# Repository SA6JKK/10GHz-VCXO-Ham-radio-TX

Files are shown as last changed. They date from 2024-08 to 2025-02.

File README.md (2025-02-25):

# 10GHz-VCXO-Ham-radio-TX
 A 10 GHz VCXO based FSK transmitter for ham radio

Goal: 0dBm to antenna. 

Goal: Output frequency between 10367-10369 MHz.  

Goal 75x120 mm PCB that fits HAMMOND 1455J1201RD 

https://se.farnell.com/hammond/1455j1201rd/pcb-box-enclosure-alum-red/dp/2469294

VCXO control from external BNC connector. FSK-CW or FSK modes. 

Aisler four layer "HD PCB" stackup for somewhat close to 50 ohms with cheap FR4 substrate. 

# Project Status: 

Schematic: Finished 

Layout: Finished and ordered

Verification: Not fully working :(

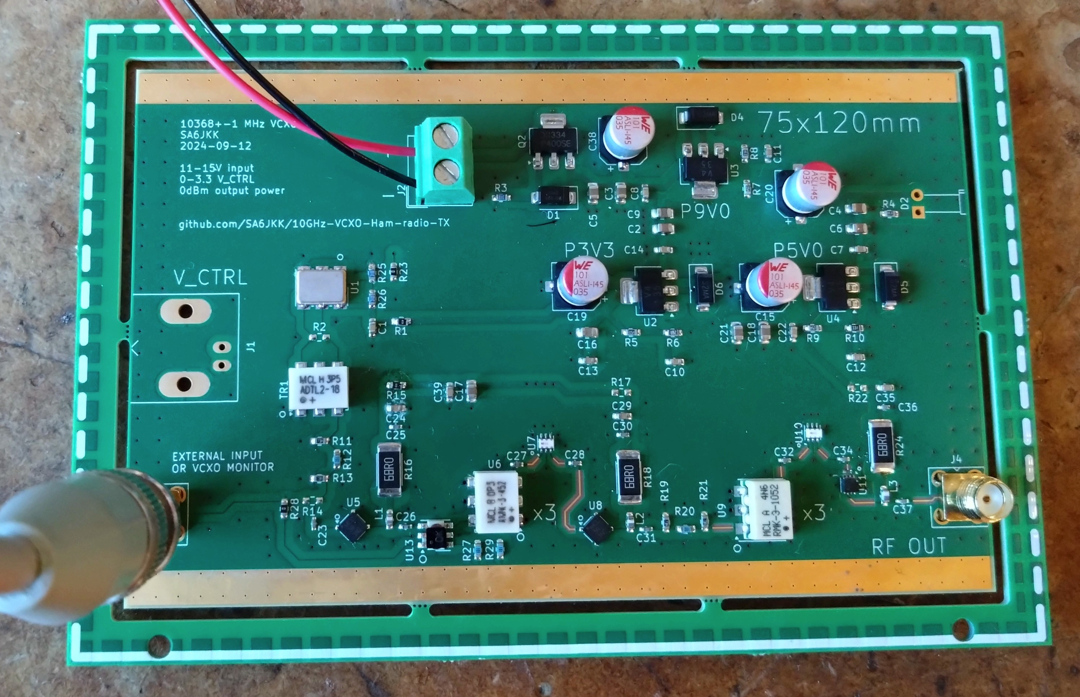
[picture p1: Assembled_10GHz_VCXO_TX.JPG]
Assembled PCB


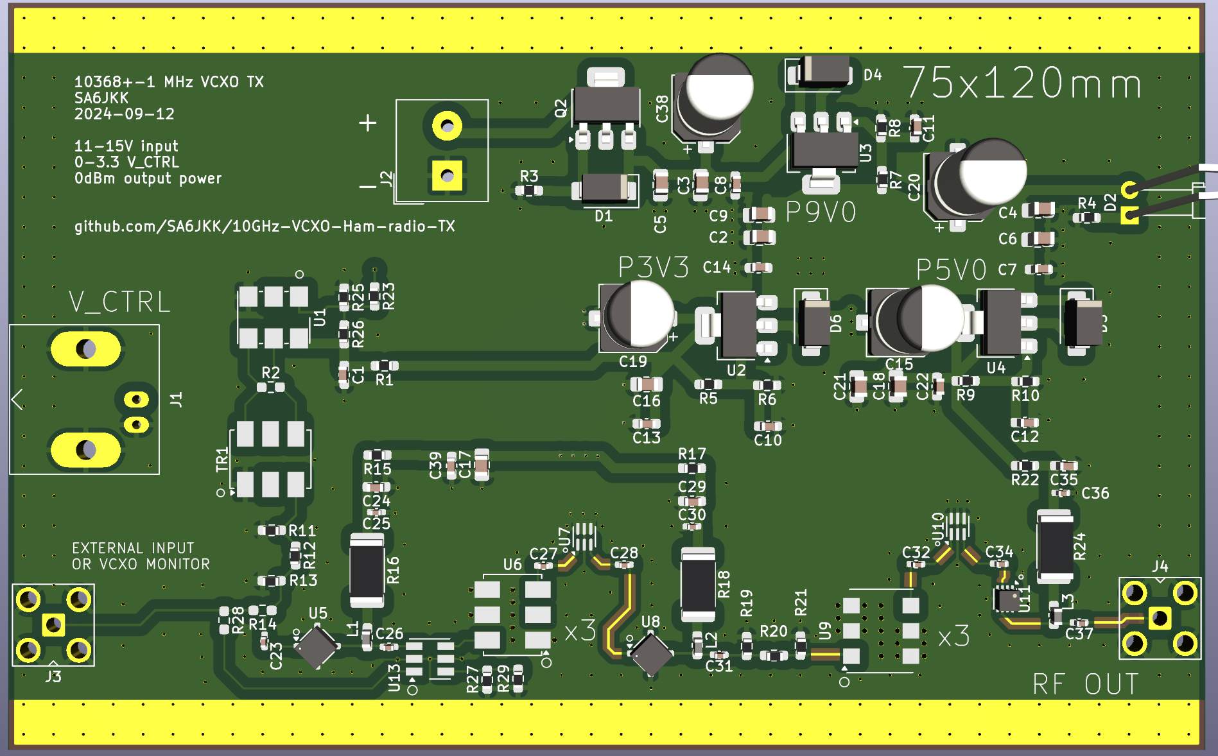
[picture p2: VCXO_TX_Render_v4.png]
Render of PCB


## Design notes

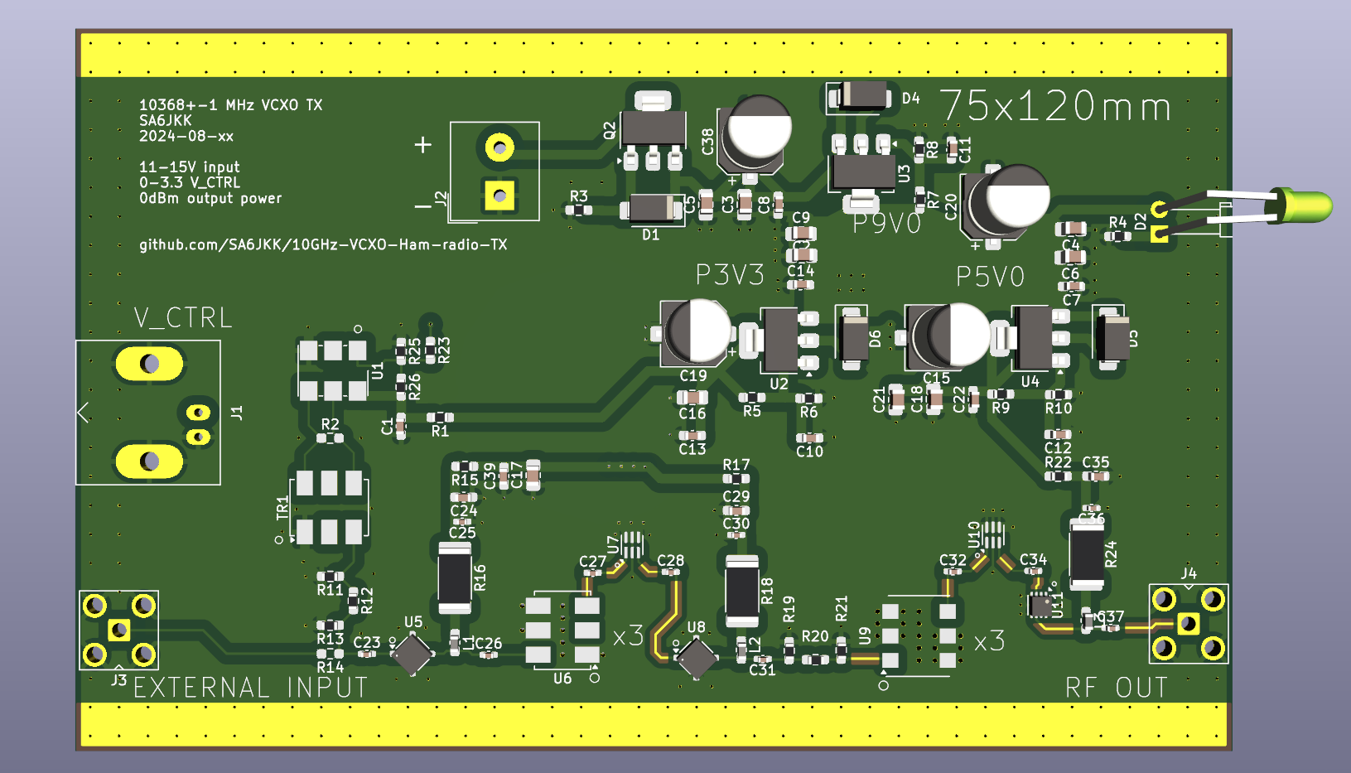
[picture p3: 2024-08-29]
VCXO_TX_Render_v2.png

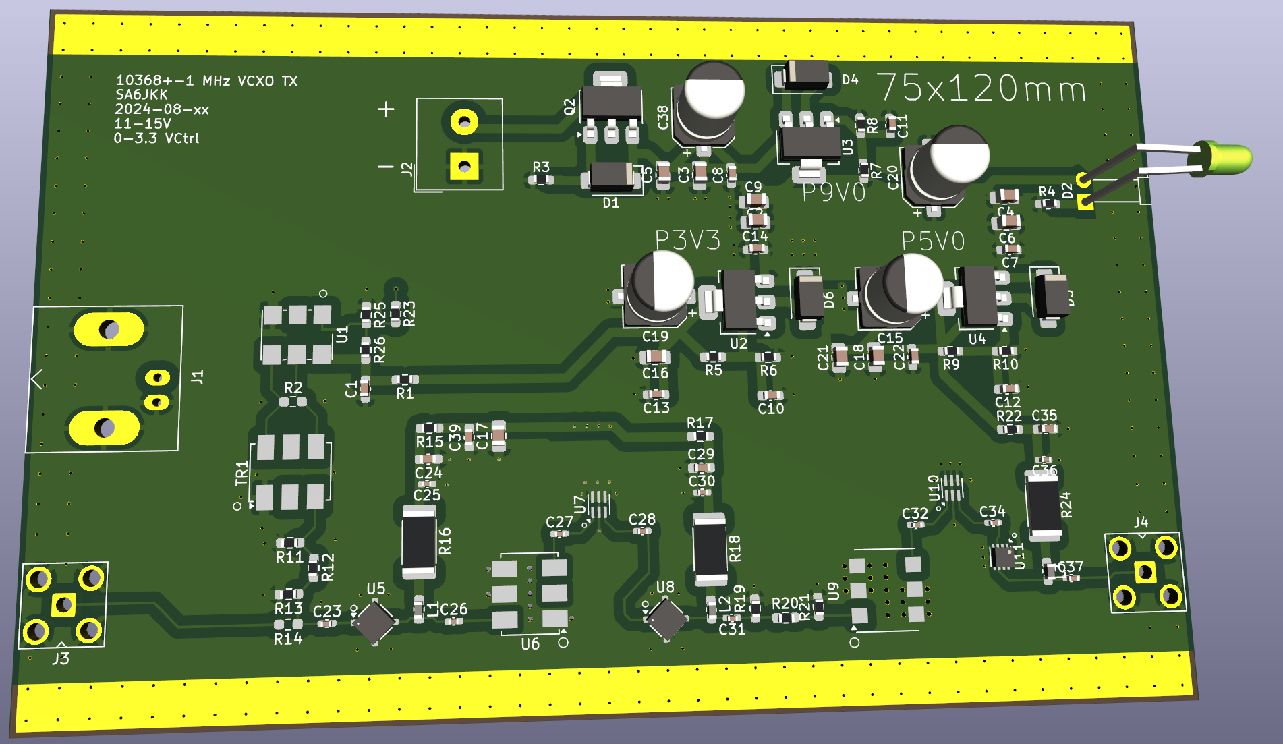
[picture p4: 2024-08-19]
VCXO_TX_Render_v1.png

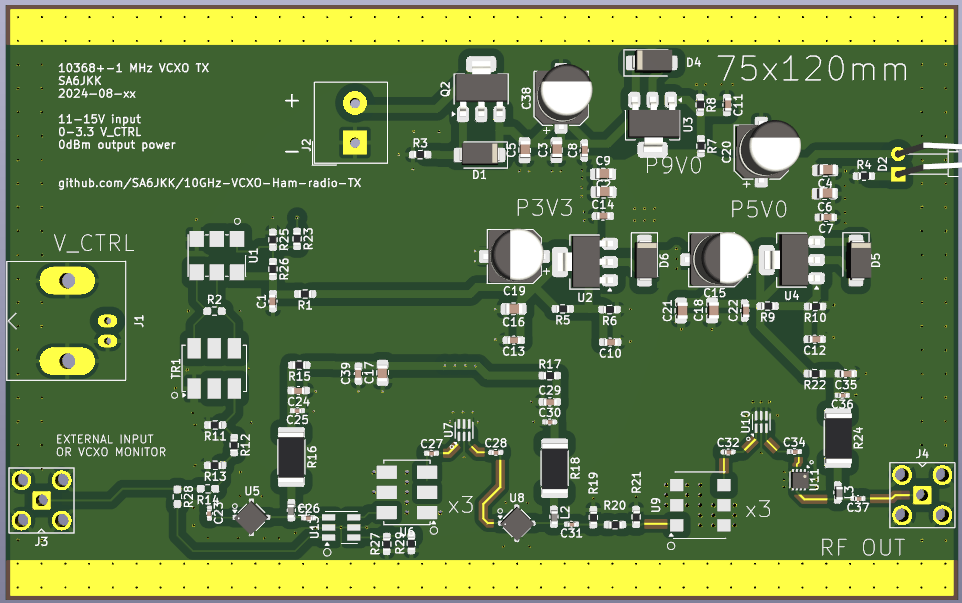
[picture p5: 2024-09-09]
VCXO_TX_Render_v3.png

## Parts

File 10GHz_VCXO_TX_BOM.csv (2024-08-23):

Reference | Value | Datasheet | Footprint | Qty | DNP
C1,C7,C8,C10,C11,C12,C13,C14,C22,C24,C29,C35,C39 | 100nF | ~ | Capacitor_SMD:C_0603_1608Metric_Pad1.08x0.95mm_HandSolder | 13
C2,C3,C4,C5,C6,C9,C16,C17,C18,C21 | 10uF | ~ | Capacitor_SMD:C_0805_2012Metric_Pad1.18x1.45mm_HandSolder | 10
C15,C19,C20,C38 | 100uF | ~ | Capacitor_SMD:CP_Elec_6.3x7.7 | 4
C23,C25,C26,C27,C28,C30,C31,C32,C34,C36,C37 | 1nF | ~ | Capacitor_SMD:C_0402_1005Metric_Pad0.74x0.62mm_HandSolder | 11
D1 | 10V | ~ | Diode_SMD:D_SMA | 1
D2 | LED | ~ | LED_THT:LED_D3.0mm_Horizontal_O6.35mm_Z10.0mm | 1
D4,D5,D6 | S2MA | https://www.farnell.com/datasheets/2863973.pdf | Diode_SMD:D_SMA | 3
J1,J3,J4 | Conn_Coaxial | ~ | -- mixed values -- | 3
J2 | Screw_Terminal_01x02 | ~ | TerminalBlock_Altech:Altech_AK100_1x02_P5.00mm | 1
L1 | 27nH | ~ | Inductor_SMD:L_0603_1608Metric_Pad1.05x0.95mm_HandSolder | 1
L2 | 10nH | ~ | Inductor_SMD:L_0603_1608Metric_Pad1.05x0.95mm_HandSolder | 1
L3 | 2.7nH | ~ | Inductor_SMD:L_0603_1608Metric_Pad1.05x0.95mm_HandSolder | 1
Q2 | DMP10H400SE | https://www.farnell.com/datasheets/2814417.pdf | Package_TO_SOT_SMD:SOT-223-3_TabPin2 | 1
R1,R15,R17,R22,R23 | 0 | ~ | Resistor_SMD:R_0603_1608Metric_Pad0.98x0.95mm_HandSolder | 5
R2 | 100 | ~ | Resistor_SMD:R_0603_1608Metric_Pad0.98x0.95mm_HandSolder | 1 | DNP
R3,R25,R26 | 10k | ~ | Resistor_SMD:R_0603_1608Metric_Pad0.98x0.95mm_HandSolder | 3
R4 | R? | ~ | Resistor_SMD:R_0603_1608Metric_Pad0.98x0.95mm_HandSolder | 1
R5,R7,R9 | 110 | ~ | Resistor_SMD:R_0603_1608Metric_Pad0.98x0.95mm_HandSolder | 3
R6 | 180 | ~ | Resistor_SMD:R_0603_1608Metric_Pad0.98x0.95mm_HandSolder | 1
R8 | 680 | ~ | Resistor_SMD:R_0603_1608Metric_Pad0.98x0.95mm_HandSolder | 1
R10 | 330 | ~ | Resistor_SMD:R_0603_1608Metric_Pad0.98x0.95mm_HandSolder | 1
R11,R13,R19,R21 | 560 | ~ | Resistor_SMD:R_0603_1608Metric_Pad0.98x0.95mm_HandSolder | 4
R12,R20 | 10 | ~ | Resistor_SMD:R_0603_1608Metric_Pad0.98x0.95mm_HandSolder | 2
R14 | 0 | ~ | Resistor_SMD:R_0603_1608Metric_Pad0.98x0.95mm_HandSolder | 1 | DNP
R16,R18,R24 | 68 | ~ | Resistor_SMD:R_2512_6332Metric_Pad1.40x3.35mm_HandSolder | 3
TR1 | ADTL2-18 2:1 | https://www.minicircuits.com/pdfs/ADTL2-18+.pdf | RF_Mini-Circuits:Mini-Circuits_CD542_H2.84mm | 1
U1 | 1152MHz | https://www.renesas.com/us/en/document/dst/xu-family-low-phase-noise-quartz-based-pll-oscillators-datasheet | Oscillator:Oscillator_SMD_IDT_JU6-6_7.0x5.0mm_P2.54mm | 1
U2,U3,U4 | TLV1117-ADJ | http://www.ti.com/lit/ds/symlink/tlv1117.pdf | Package_TO_SOT_SMD:SOT-223-3_TabPin2 | 3
U5,U8 | LEE-59+ | https://www.mouser.se/datasheet/2/1030/LEE_59_2b-1700827.pdf | Package_DFN_QFN:Mini-Circuits_FG873-4_3x3mm | 2
U6 | AMK-3-452+ | https://www.mouser.se/datasheet/2/1030/AMK_3_452_2b-2936698.pdf | RF_Mini-Circuits:Mini-Circuits_CD542_LandPatternPL-052 | 1
U7 | HFCG-2200+ | https://www.mouser.se/datasheet/2/1030/HFCG_2200_2b-3077494.pdf | OptoDevice:Broadcom_DFN-6_2x2mm_P0.65mm | 1
U9 | RMK-3-1052+ | https://www.mouser.se/datasheet/2/1030/RMK_3_1052_2b-3305585.pdf | RF_Mini-Circuits:Mini-Circuits_TT1224_LandPatternPL-258_ClockwisePinNumbering | 1
U10 | HFCG-4400+ | https://www.mouser.se/datasheet/2/1030/HFCG_4400_2b-2256271.pdf | OptoDevice:Broadcom_DFN-6_2x2mm_P0.65mm | 1
U11 | PMA2-123LN5+ | https://www.mouser.se/datasheet/2/1030/PMA2_123LN5_2b-1701048.pdf | Package_DFN_QFN:DFN-8-1EP_2x2mm_P0.5mm_EP0.6x1.2mm | 1

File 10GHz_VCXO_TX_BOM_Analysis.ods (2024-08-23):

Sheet: BOM_v3
Reference | Value | Datasheet | Footprint | Qty | DNP | Ordered
C1,C7,C8,C10,C11,C12,C13,C14,C22,C24,C29,C35,C39 | 100nF | ~ | Capacitor_SMD:C_0603_1608Metric_Pad1.08x0.95mm_HandSolder | 13 |  | 100
C2,C3,C4,C5,C6,C9,C16,C17,C18,C21 | 10uF | ~ | Capacitor_SMD:C_0805_2012Metric_Pad1.18x1.45mm_HandSolder | 10 |  | 30
C15,C19,C20,C38 | 100uF | ~ | Capacitor_SMD:CP_Elec_6.3x7.7 | 4 |  | 20
C23,C25,C26,C27,C28,C30,C31,C32,C34,C36,C37 | 1nF | ~ | Capacitor_SMD:C_0402_1005Metric_Pad0.74x0.62mm_HandSolder | 11 |  | 30
D1 | 10V | ~ | Diode_SMD:D_SMA | 1 |  | 10
D2 | LED | ~ | LED_THT:LED_D3.0mm_Horizontal_O6.35mm_Z10.0mm | 1 |  | Inventory
D4,D5,D6 | S2MA | https://www.farnell.com/datasheets/2863973.pdf | Diode_SMD:D_SMA | 3 |  | 30
J1,J3,J4 | Conn_Coaxial | ~ | -- mixed values -- | 3 |  | Inventory
J2 | Screw_Terminal_01x02 | ~ | TerminalBlock_Altech:Altech_AK100_1x02_P5.00mm | 1 |  | Inventory
L1 | 27nH | ~ | Inductor_SMD:L_0603_1608Metric_Pad1.05x0.95mm_HandSolder | 1 |  | 20
L2 | 10nH | ~ | Inductor_SMD:L_0603_1608Metric_Pad1.05x0.95mm_HandSolder | 1 |  | 20
L3 | 2.7nH | ~ | Inductor_SMD:L_0603_1608Metric_Pad1.05x0.95mm_HandSolder | 1 |  | 20
Q2 | DMP10H400SE | https://www.farnell.com/datasheets/2814417.pdf | Package_TO_SOT_SMD:SOT-223-3_TabPin2 | 1 |  | 10
R1,R15,R17,R22,R23 | 0 | ~ | Resistor_SMD:R_0603_1608Metric_Pad0.98x0.95mm_HandSolder | 5 |  | Inventory
R2 | 100 | ~ | Resistor_SMD:R_0603_1608Metric_Pad0.98x0.95mm_HandSolder | 1 | DNP | Inventory
R3,R25,R26 | 10k | ~ | Resistor_SMD:R_0603_1608Metric_Pad0.98x0.95mm_HandSolder | 3 |  | Inventory
R4 | R? | ~ | Resistor_SMD:R_0603_1608Metric_Pad0.98x0.95mm_HandSolder | 1 |  | Inventory
R5,R7,R9 | 110 | ~ | Resistor_SMD:R_0603_1608Metric_Pad0.98x0.95mm_HandSolder | 3 |  | Inventory
R6 | 180 | ~ | Resistor_SMD:R_0603_1608Metric_Pad0.98x0.95mm_HandSolder | 1 |  | Inventory
R8 | 680 | ~ | Resistor_SMD:R_0603_1608Metric_Pad0.98x0.95mm_HandSolder | 1 |  | Inventory
R10 | 330 | ~ | Resistor_SMD:R_0603_1608Metric_Pad0.98x0.95mm_HandSolder | 1 |  | Inventory
R11,R13,R19,R21 | 560 | ~ | Resistor_SMD:R_0603_1608Metric_Pad0.98x0.95mm_HandSolder | 4 |  | Inventory
R12,R20 | 10 | ~ | Resistor_SMD:R_0603_1608Metric_Pad0.98x0.95mm_HandSolder | 2 |  | Inventory
R14 | 0 | ~ | Resistor_SMD:R_0603_1608Metric_Pad0.98x0.95mm_HandSolder | 1 | DNP | Inventory
R16,R18,R24 | 68 | ~ | Resistor_SMD:R_2512_6332Metric_Pad1.40x3.35mm_HandSolder | 3 |  | Inventory
TR1 | ADTL2-18 2:1 | https://www.minicircuits.com/pdfs/ADTL2-18+.pdf | RF_Mini-Circuits:Mini-Circuits_CD542_H2.84mm | 1 |  | 3
U1 | 1152MHz | https://www.renesas.com/us/en/document/dst/xu-family-low-phase-noise-quartz-based-pll-oscillators-datasheet | Oscillator:Oscillator_SMD_IDT_JU6-6_7.0x5.0mm_P2.54mm | 1 |  | 5
U2,U3,U4 | TLV1117-ADJ | http://www.ti.com/lit/ds/symlink/tlv1117.pdf | Package_TO_SOT_SMD:SOT-223-3_TabPin2 | 3 |  | 15
U5,U8 | LEE-59+ | https://www.mouser.se/datasheet/2/1030/LEE_59_2b-1700827.pdf | Package_DFN_QFN:Mini-Circuits_FG873-4_3x3mm | 2 |  | Inventory
U6 | AMK-3-452+ | https://www.mouser.se/datasheet/2/1030/AMK_3_452_2b-2936698.pdf | RF_Mini-Circuits:Mini-Circuits_CD542_LandPatternPL-052 | 1 |  | 3
U7 | HFCG-2200+ | https://www.mouser.se/datasheet/2/1030/HFCG_2200_2b-3077494.pdf | OptoDevice:Broadcom_DFN-6_2x2mm_P0.65mm | 1 |  | 3
U9 | RMK-3-1052+ | https://www.mouser.se/datasheet/2/1030/RMK_3_1052_2b-3305585.pdf | RF_Mini-Circuits:Mini-Circuits_TT1224_LandPatternPL-258_ClockwisePinNumbering | 1 |  | 3
U10 | HFCG-4400+ | https://www.mouser.se/datasheet/2/1030/HFCG_4400_2b-2256271.pdf | OptoDevice:Broadcom_DFN-6_2x2mm_P0.65mm | 1 |  | 3
U11 | PMA2-123LN5+ | https://www.mouser.se/datasheet/2/1030/PMA2_123LN5_2b-1701048.pdf | Package_DFN_QFN:DFN-8-1EP_2x2mm_P0.5mm_EP0.6x1.2mm | 1 |  | 3

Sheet: BOM_v2
Reference | Value | Datasheet | Footprint | Qty | DNP | Cost estimate | Total cost
C1,C7,C8,C10,C11,C12,C13,C14,C22,C24,C29,C35,C39 | 100nF | ~ | Capacitor_SMD:C_0603_1608Metric_Pad1.08x0.95mm_HandSolder | 13 |  | 1 | 13
C2,C3,C4,C5,C6,C9,C18,C21 | 10uF | ~ | Capacitor_SMD:C_0603_1608Metric_Pad1.08x0.95mm_HandSolder | 8 |  | 1 | 8
C15,C19,C20,C38 | 100uF | ~ | Capacitor_SMD:CP_Elec_5x5.7 | 4 |  | 1 | 4
C16,C17 | >1u | ~ | Capacitor_SMD:C_0603_1608Metric_Pad1.08x0.95mm_HandSolder | 2 |  | 1 | 2
C23,C25,C26,C27,C28,C30,C31,C32,C33,C34,C36,C37 | 1nF | ~ | Capacitor_SMD:C_0402_1005Metric_Pad0.74x0.62mm_HandSolder | 12 |  | 1 | 12
D1 | 10V | ~ | Package_TO_SOT_SMD:SOT-223-3_TabPin2 | 1 |  | 2 | 2
D3 | LED | ~ | LED_THT:LED_D3.0mm_Horizontal_O6.35mm_Z10.0mm | 1 |  | 2 | 2
D7,D8,D9 | 1N4002 | http://www.vishay.com/docs/88503/1n4001.pdf | Diode_THT:D_DO-41_SOD81_P10.16mm_Horizontal | 3 |  | 2 | 6
J1,J3,J4 | Conn_Coaxial | ~ | -- mixed values -- | 3 |  | 50 | 150
J2 | Screw_Terminal_01x02 | ~ | TerminalBlock_Altech:Altech_AK100_1x02_P5.00mm | 1 |  | 2 | 2
L1,L2,L3 | L | ~ | Inductor_SMD:L_0603_1608Metric_Pad1.05x0.95mm_HandSolder | 3 |  | 3 | 9
Q2 | DMP10H400SE | https://www.farnell.com/datasheets/2814417.pdf | Package_TO_SOT_SMD:SOT-223-3_TabPin2 | 1 |  | 6 | 6
R1,R14,R15,R17,R22 | 0 | ~ | Resistor_SMD:R_0603_1608Metric_Pad0.98x0.95mm_HandSolder | 5 |  | 1 | 5
R2 | 100 | ~ | Resistor_SMD:R_0603_1608Metric_Pad0.98x0.95mm_HandSolder | 1 | DNP | 1 | 1
R3,R4 | R? | ~ | Resistor_SMD:R_0603_1608Metric_Pad0.98x0.95mm_HandSolder | 2 |  | 1 | 2
R5,R7,R9 | 110 | ~ | Resistor_SMD:R_0603_1608Metric_Pad0.98x0.95mm_HandSolder | 3 |  | 1 | 3
R6 | 180 | ~ | Resistor_SMD:R_0603_1608Metric_Pad0.98x0.95mm_HandSolder | 1 |  | 1 | 1
R8 | 680 | ~ | Resistor_SMD:R_0603_1608Metric_Pad0.98x0.95mm_HandSolder | 1 |  | 1 | 1
R10 | 330 | ~ | Resistor_SMD:R_0603_1608Metric_Pad0.98x0.95mm_HandSolder | 1 |  | 1 | 1
R11,R13,R19,R21 | 560 | ~ | Resistor_SMD:R_0603_1608Metric_Pad0.98x0.95mm_HandSolder | 4 |  | 1 | 4
R12,R20 | 10 | ~ | Resistor_SMD:R_0603_1608Metric_Pad0.98x0.95mm_HandSolder | 2 |  | 1 | 2
R16,R18,R24 | 68 | ~ | Resistor_SMD:R_2512_6332Metric_Pad1.40x3.35mm_HandSolder | 3 |  | 5 | 15
TR1 | ADTL2-18 2:1 | https://www.minicircuits.com/pdfs/ADTL2-18+.pdf | RF_Mini-Circuits:Mini-Circuits_CD542_H2.84mm | 1 |  | 69 | 69
U1 | 1152MHz | https://www.renesas.com/us/en/document/dst/xu-family-low-phase-noise-quartz-based-pll-oscillators-datasheet | Oscillator:Oscillator_SMD_IDT_JU6-6_7.0x5.0mm_P2.54mm | 1 |  | 68 | 68
U2,U3,U4 | TLV1117-ADJ | http://www.ti.com/lit/ds/symlink/tlv1117.pdf | Package_TO_SOT_SMD:SOT-223-3_TabPin2 | 3 |  | 5 | 15
U5,U8 | LEE-59+ | https://www.mouser.se/datasheet/2/1030/LEE_59_2b-1700827.pdf | Package_DFN_QFN:Mini-Circuits_FG873-4_3x3mm | 2 |  | 34 | 68
U6 | AMK-3-452+ | https://www.mouser.se/datasheet/2/1030/AMK_3_452_2b-2936698.pdf | RF_Mini-Circuits:Mini-Circuits_CD542_LandPatternPL-052 | 1 |  | 104 | 104
U7 | HFCG-2200+ | https://www.mouser.se/datasheet/2/1030/HFCG_2200_2b-3077494.pdf | OptoDevice:Broadcom_DFN-6_2x2mm_P0.65mm | 1 |  | 73 | 73
U9 | RMK-3-1052+ | https://www.mouser.se/datasheet/2/1030/RMK_3_1052_2b-3305585.pdf | RF_Mini-Circuits:Mini-Circuits_TT1224_LandPatternPL-258_ClockwisePinNumbering | 1 |  | 149 | 149
U10 | HFCG-4400+ | https://www.mouser.se/datasheet/2/1030/HFCG_4400_2b-2256271.pdf | OptoDevice:Broadcom_DFN-6_2x2mm_P0.65mm | 1 |  | 73 | 73
U11 | PMA2-123LN5+ | https://www.mouser.se/datasheet/2/1030/PMA2_123LN5_2b-1701048.pdf | Package_DFN_QFN:DFN-8-1EP_2x2mm_P0.5mm_EP0.6x1.2mm | 1 |  | 194 | 194
 |  |  |  | Last update | 2024-07-28 |  | 1015 | kr

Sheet: BOM_v1
Reference | Value | Datasheet | Footprint | Qty | DNP | Cost estimate | Total cost
C1,C4,C5,C6,C11,C12,C13,C16,C18 | 100nF | ~ | Capacitor_SMD:C_0603_1608Metric_Pad1.08x0.95mm_HandSolder | 9 |  | 1 | 9
C2,C3,C9,C10 | 10uF | ~ | Capacitor_SMD:C_0603_1608Metric_Pad1.08x0.95mm_HandSolder | 4 |  | 1 | 4
C7,C14 | >1u | ~ | Capacitor_SMD:C_0603_1608Metric_Pad1.08x0.95mm_HandSolder | 2 |  | 1 | 2
C8,C15 | 100uF | ~ | Capacitor_SMD:CP_Elec_5x5.7 | 2 |  | 1 | 2
C17,C19,C20,C21 | 1nF | ~ | Capacitor_SMD:C_0402_1005Metric_Pad0.74x0.62mm_HandSolder | 4 |  | 1 | 4
D1,D2 | 1N4002 | http://www.vishay.com/docs/88503/1n4001.pdf | Diode_THT:D_DO-41_SOD81_P10.16mm_Horizontal | 2 |  | 2 | 4
J1,J3 | Screw_Terminal_01x02 | ~ | TerminalBlock_Altech:Altech_AK100_1x02_P5.00mm | 2 |  | 2 | 4
J2 | Conn_Coaxial | ~ | Connector_Coaxial:SMA_Amphenol_901-143_Horizontal | 1 |  | 50 | 50
L1,L2 | L | ~ | Inductor_SMD:L_0603_1608Metric_Pad1.05x0.95mm_HandSolder | 2 |  | 3 | 6
R1 | 100 | ~ | Resistor_SMD:R_0603_1608Metric_Pad0.98x0.95mm_HandSolder | 1 | DNP | 1 | 1
R2,R7 | 110 | ~ | Resistor_SMD:R_0603_1608Metric_Pad0.98x0.95mm_HandSolder | 2 |  | 1 | 2
R3 | 180 | ~ | Resistor_SMD:R_0603_1608Metric_Pad0.98x0.95mm_HandSolder | 1 |  | 1 | 1
R4,R6,R11,R13 | 560 | ~ | Resistor_SMD:R_0603_1608Metric_Pad0.98x0.95mm_HandSolder | 4 |  | 1 | 4
R5,R12 | 10 | ~ | Resistor_SMD:R_0603_1608Metric_Pad0.98x0.95mm_HandSolder | 2 |  | 1 | 2
R8 | 680 | ~ | Resistor_SMD:R_0603_1608Metric_Pad0.98x0.95mm_HandSolder | 1 |  | 1 | 1
R9,R10 | 68 | ~ | Resistor_SMD:R_2512_6332Metric_Pad1.40x3.35mm_HandSolder | 2 |  | 5 | 10
R14,R15,R16 | 0 | ~ | Resistor_SMD:R_0603_1608Metric_Pad0.98x0.95mm_HandSolder | 3 |  | 1 | 3
TR1 | ADTL2-18 2:1 | https://www.minicircuits.com/pdfs/ADTL2-18+.pdf | RF_Mini-Circuits:Mini-Circuits_CD542_H2.84mm | 1 |  | 69 | 69
U1,U5 | TLV1117-ADJ | http://www.ti.com/lit/ds/symlink/tlv1117.pdf | Package_TO_SOT_SMD:SOT-223-3_TabPin2 | 2 |  | 5 | 10
U2 | 1152MHz | https://www.renesas.com/us/en/document/dst/xu-family-low-phase-noise-quartz-based-pll-oscillators-datasheet | Oscillator:Oscillator_SMD_IDT_JU6-6_7.0x5.0mm_P2.54mm | 1 |  | 68 | 68
U3 | AMK-3-452+ | https://www.mouser.se/datasheet/2/1030/AMK_3_452_2b-2936698.pdf | RF_Mini-Circuits:Mini-Circuits_CD542_LandPatternPL-052 | 1 |  | 104 | 104
U4 | RMK-3-1052+ | https://www.mouser.se/datasheet/2/1030/RMK_3_1052_2b-3305585.pdf | RF_Mini-Circuits:Mini-Circuits_TT1224_LandPatternPL-258_ClockwisePinNumbering | 1 |  | 149 | 149
U6,U7 | LEE-59+ | https://www.mouser.se/datasheet/2/1030/LEE_59_2b-1700827.pdf | Package_DFN_QFN:Mini-Circuits_FG873-4_3x3mm | 2 |  | 34 | 68
 |  |  |  | Last update | 2024-06-24 |  | 577 | kr

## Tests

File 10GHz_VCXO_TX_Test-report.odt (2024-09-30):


# Power

12V 250(?) mA, greater than 12V 188 mA expected

P9V0 OK

P5V0 OK

P3V3 OK

# TX_VCXO

Frequency OK, 1152 Mhz

# X3_IF_Multiplier

Coupler output 8dBm, 4-5 dB more than expected

Update schematic R11, R12, R13 to lower power into U5.

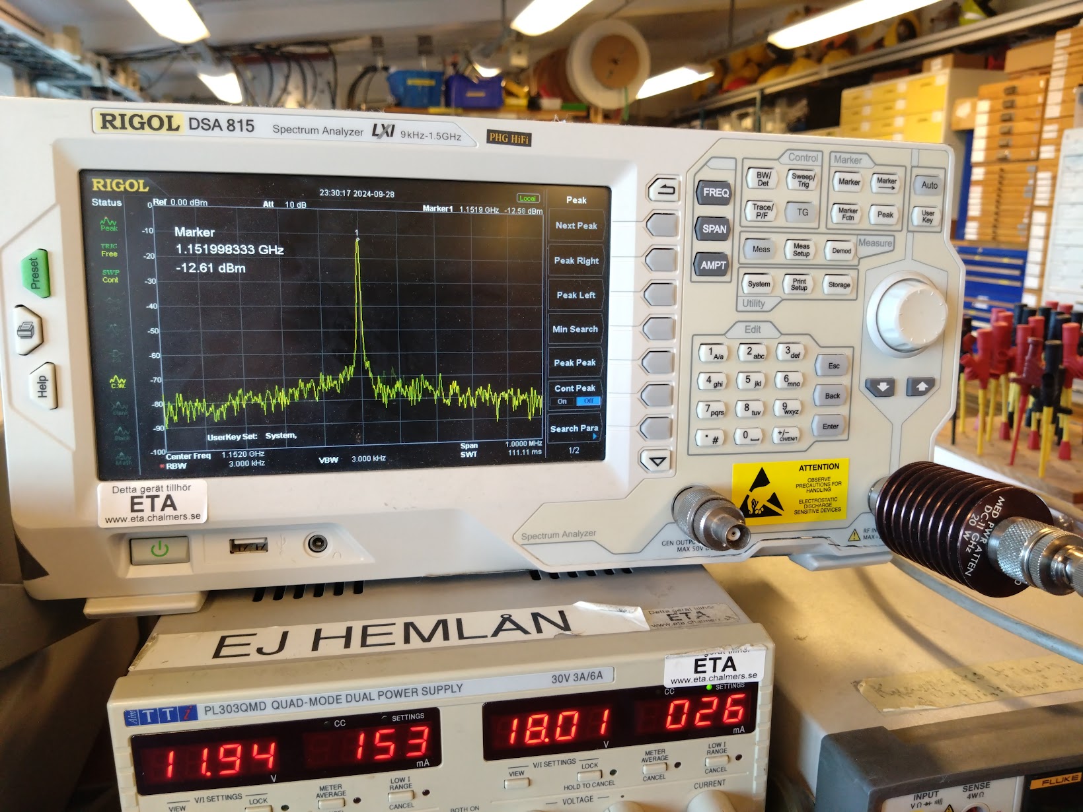
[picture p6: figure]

Spectrum after U6 OK

Check again with soldered SMA cable. Level uncertain

# X3_Rf_Multiplier

Spectrum after U9 (RMK-3-1052+) OK

Check again with soldered SMA cable. Level uncertain

# RF_PA

Output from U11 NOK!

  8. GHz, 5.75 GHz etc. generated after U11

Looks like oscillation!

10.386 GHz 30 dB lower level than expected.

4.7V lower than expected, around 2.7V -> more power consumption than estimated

Main oscillation 14.24 GHz even after changing amplifier.

Finger on amplifier lower all output levels

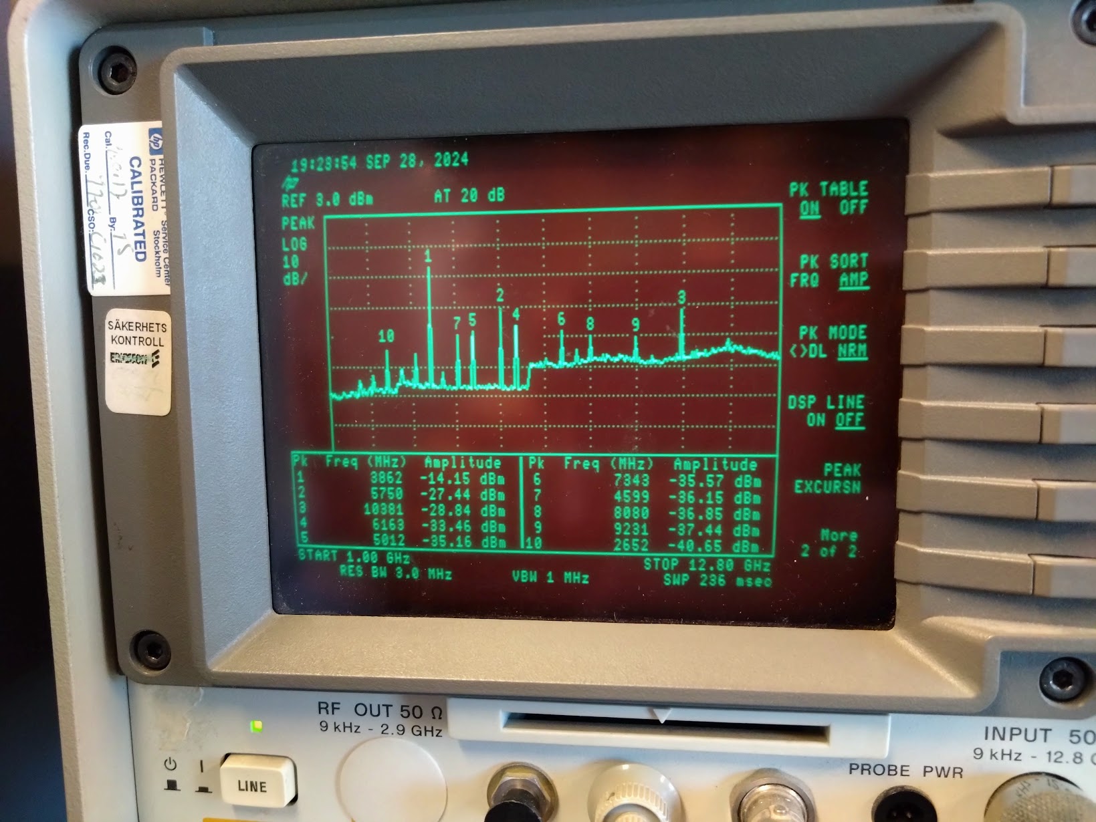
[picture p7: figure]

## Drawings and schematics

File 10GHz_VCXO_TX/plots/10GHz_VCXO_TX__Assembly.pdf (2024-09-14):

1 | 2 | 3 | 4 | 5 | 6

A

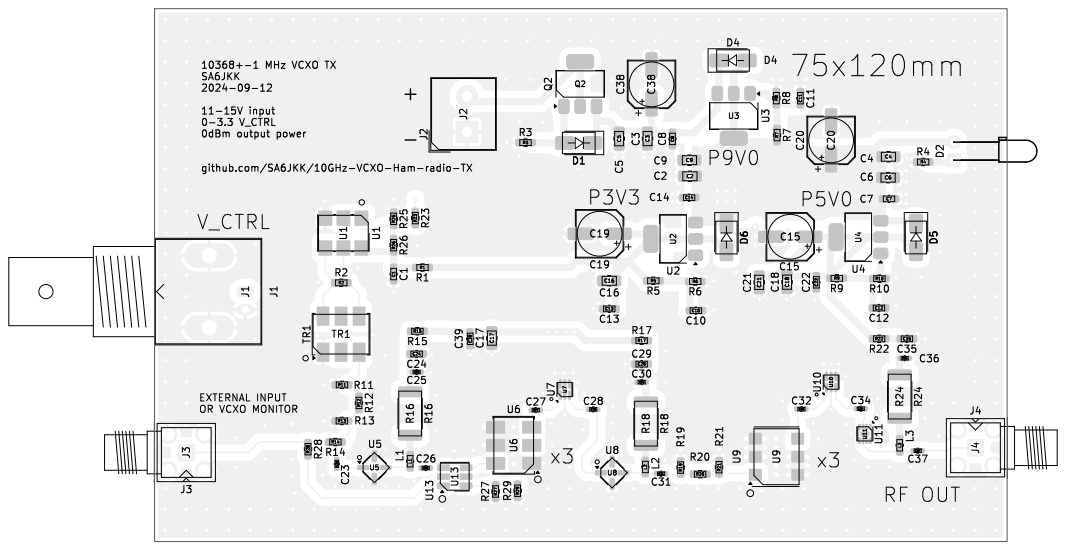
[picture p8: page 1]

EXTERNAL INPUT OR VCXO MONITOR

1 | 2 | 3 | 4 | 5 | 6

A

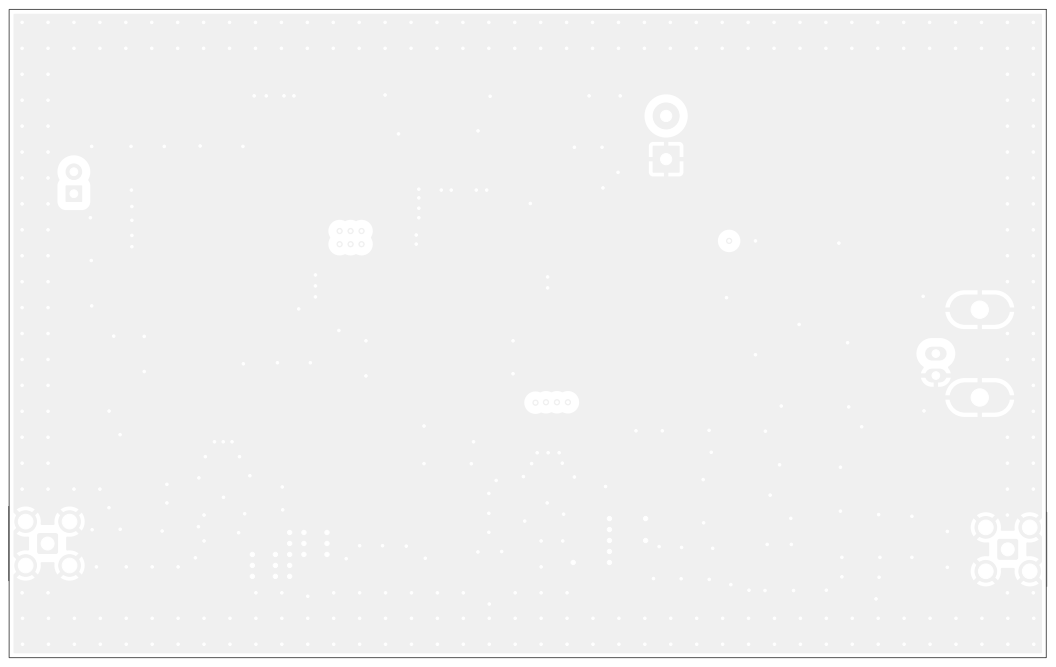
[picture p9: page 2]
D Date: KiCad; E.D.A. 8.0.2 Size: A4; Rev:

Id: 1/1 Title: File: 10GHz_VCXO_TX.kicad_pcb Sheet:

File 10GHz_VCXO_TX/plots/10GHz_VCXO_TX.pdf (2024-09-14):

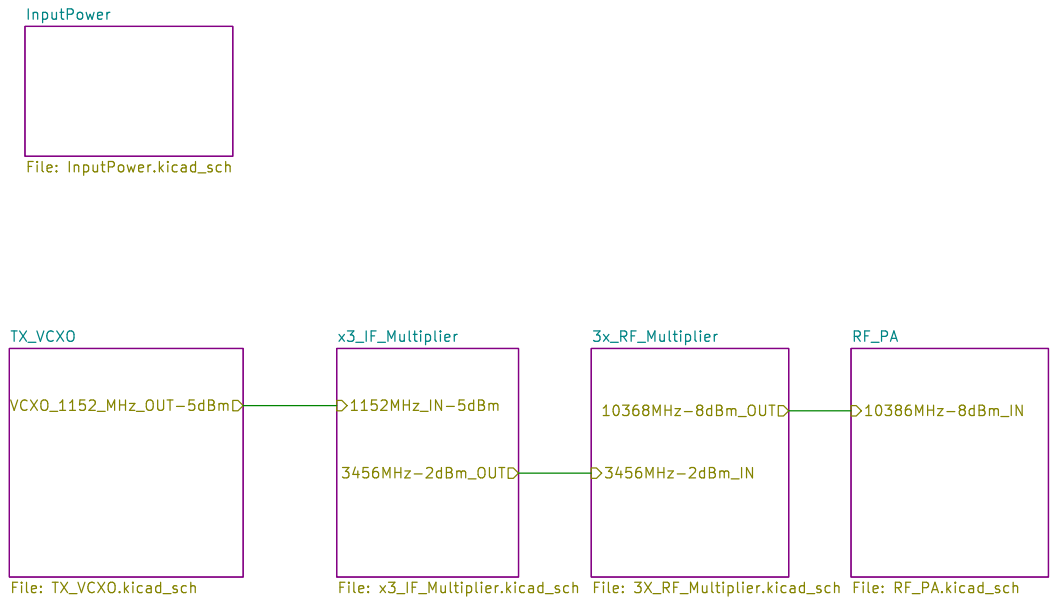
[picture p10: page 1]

Id: 1/6 Title: File: 10GHz_VCXO_TX.kicad_sch Sheet: /

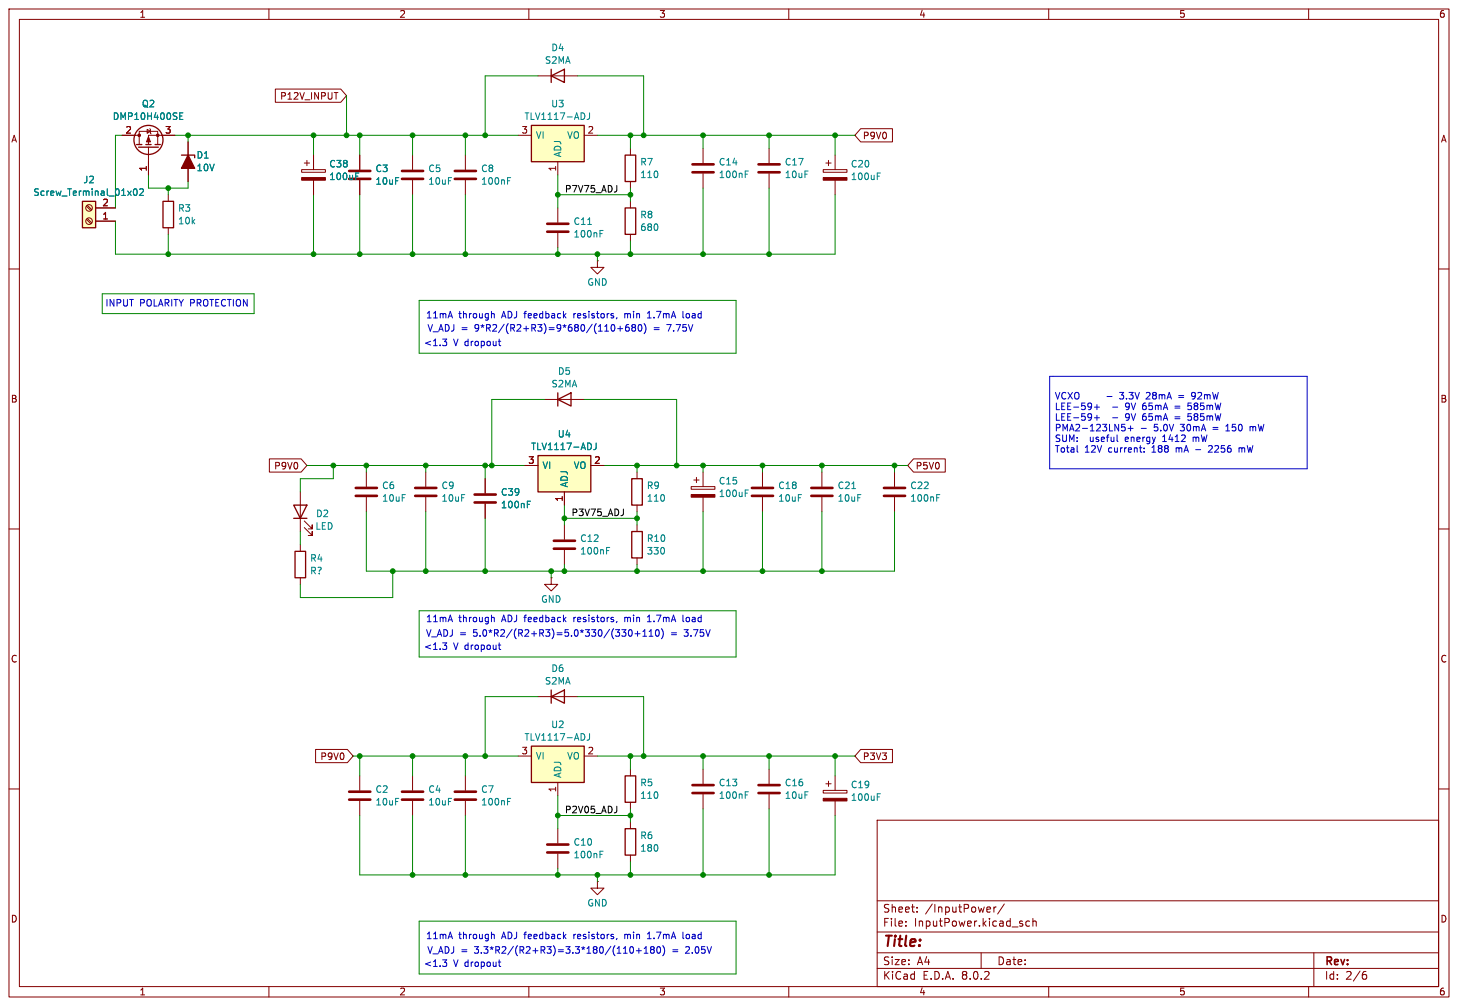
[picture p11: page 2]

Id: 2/6 Title: File: InputPower.kicad_sch Sheet: /InputPower/ GND

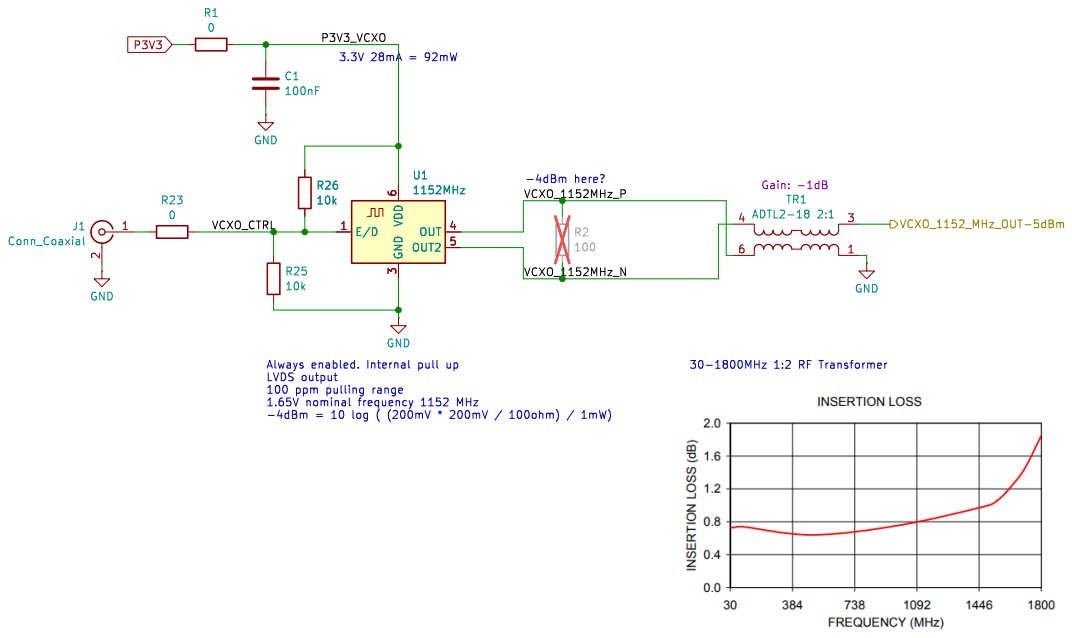
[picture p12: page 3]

Id: 3/6 Title: File: TX_VCXO.kicad_sch Sheet: /TX_VCXO/

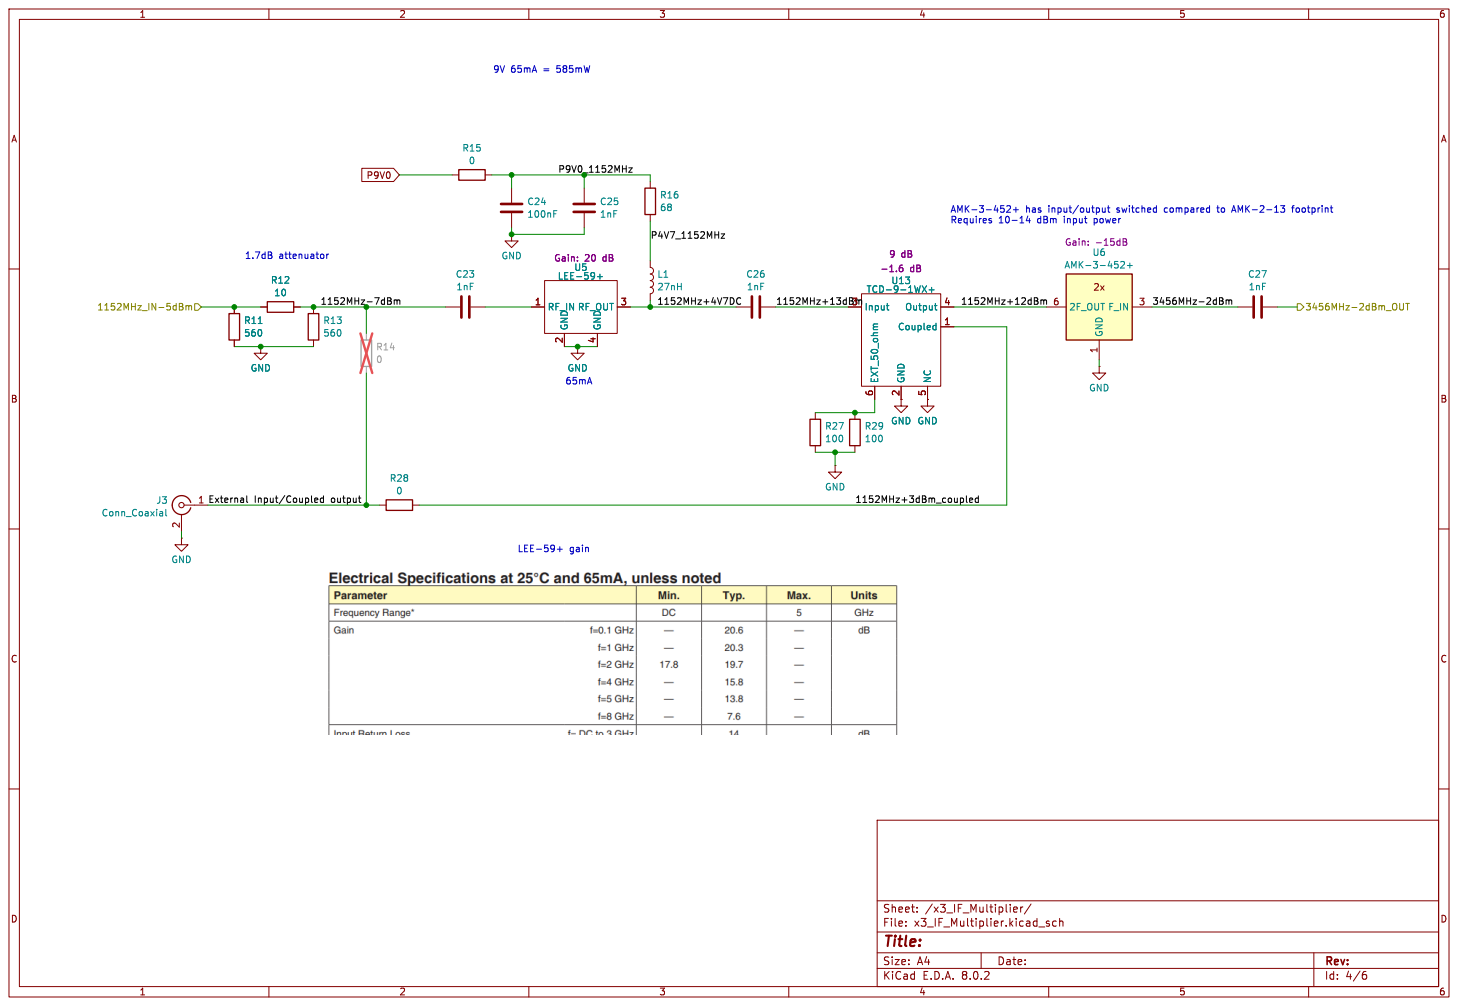
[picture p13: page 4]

LEE-59+ Gain: 20 dB GND

Id: 4/6 Title: File: x3_IF_Multiplier.kicad_sch Sheet: /x3_IF_Multiplier/

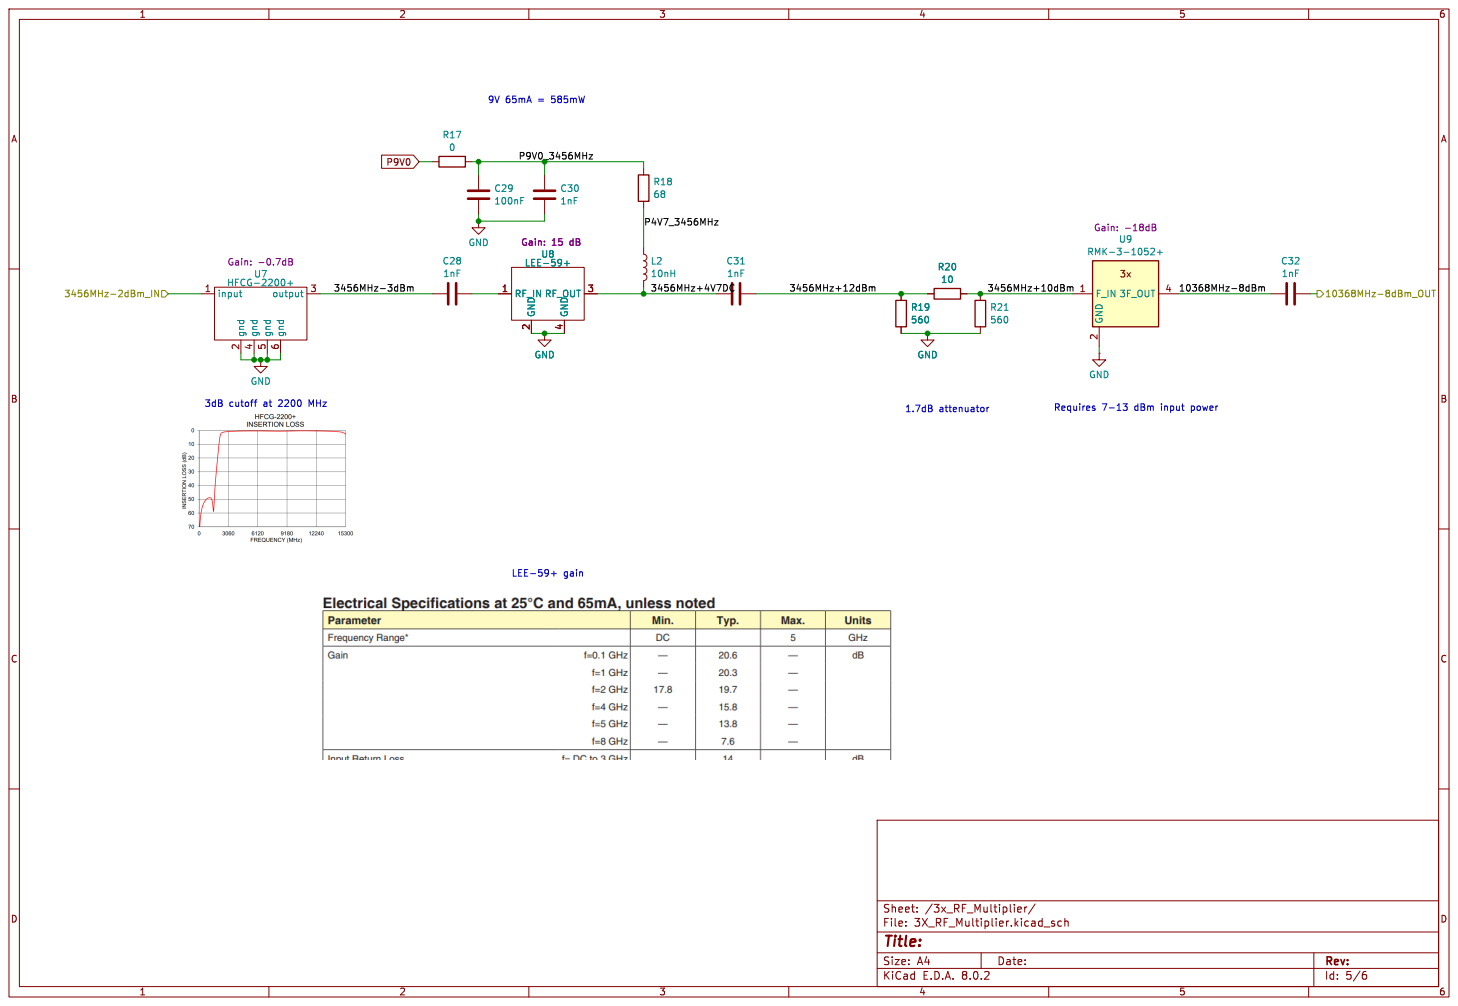
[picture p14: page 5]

Id: 5/6 Title: File: 3X_RF_Multiplier.kicad_sch Sheet: /3x_RF_Multiplier/

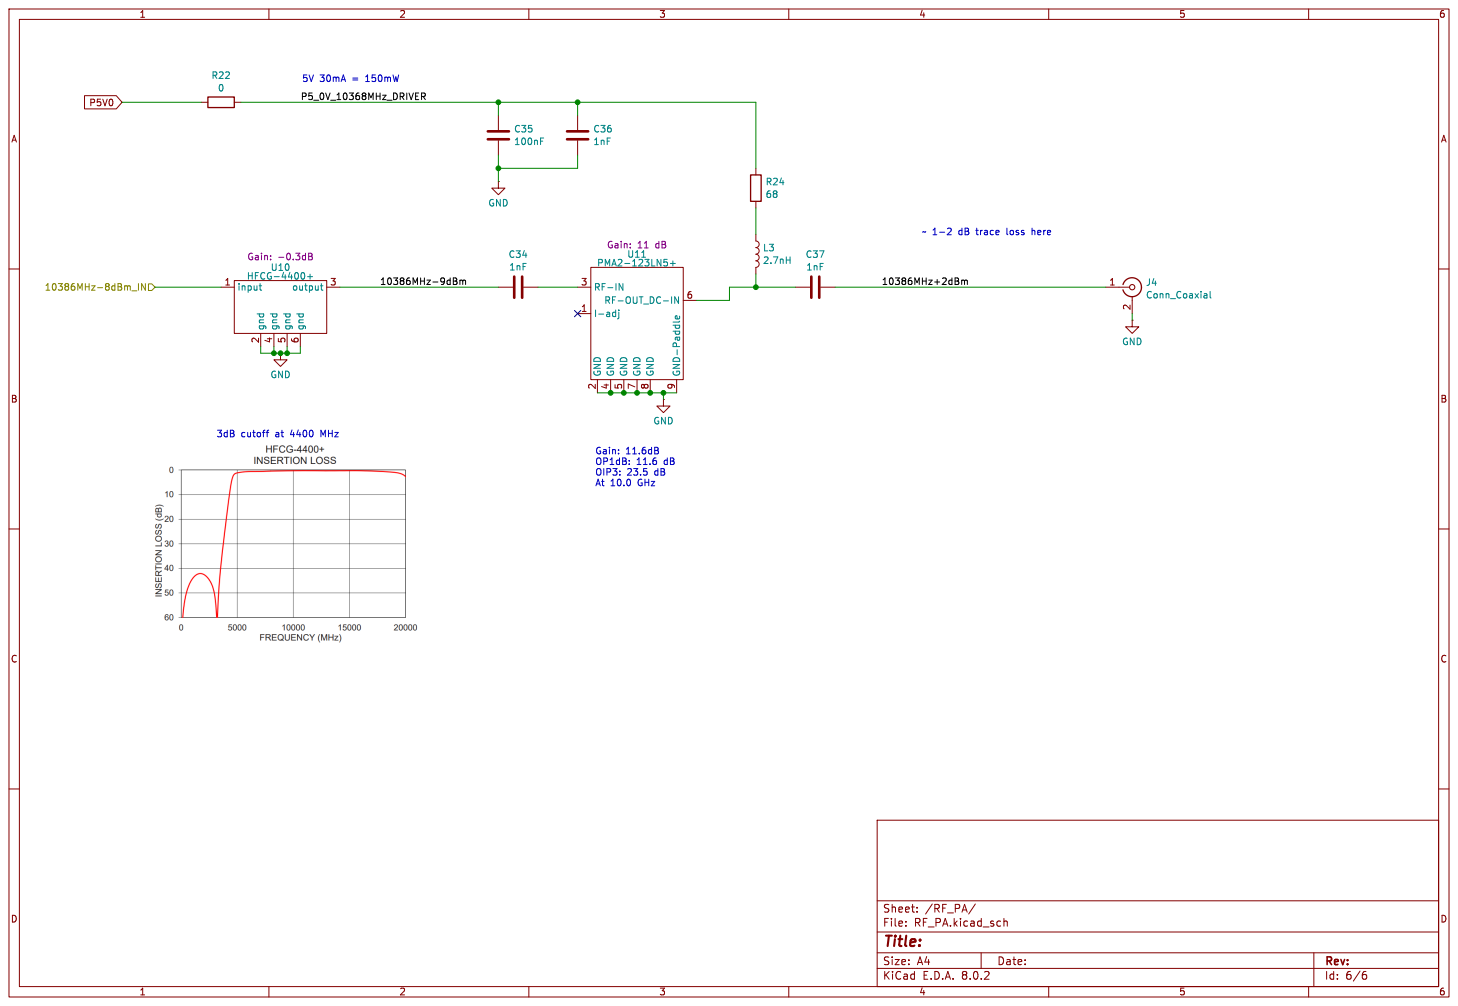
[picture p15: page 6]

Id: 6/6 Title: File: RF_PA.kicad_sch Sheet: /RF_PA/

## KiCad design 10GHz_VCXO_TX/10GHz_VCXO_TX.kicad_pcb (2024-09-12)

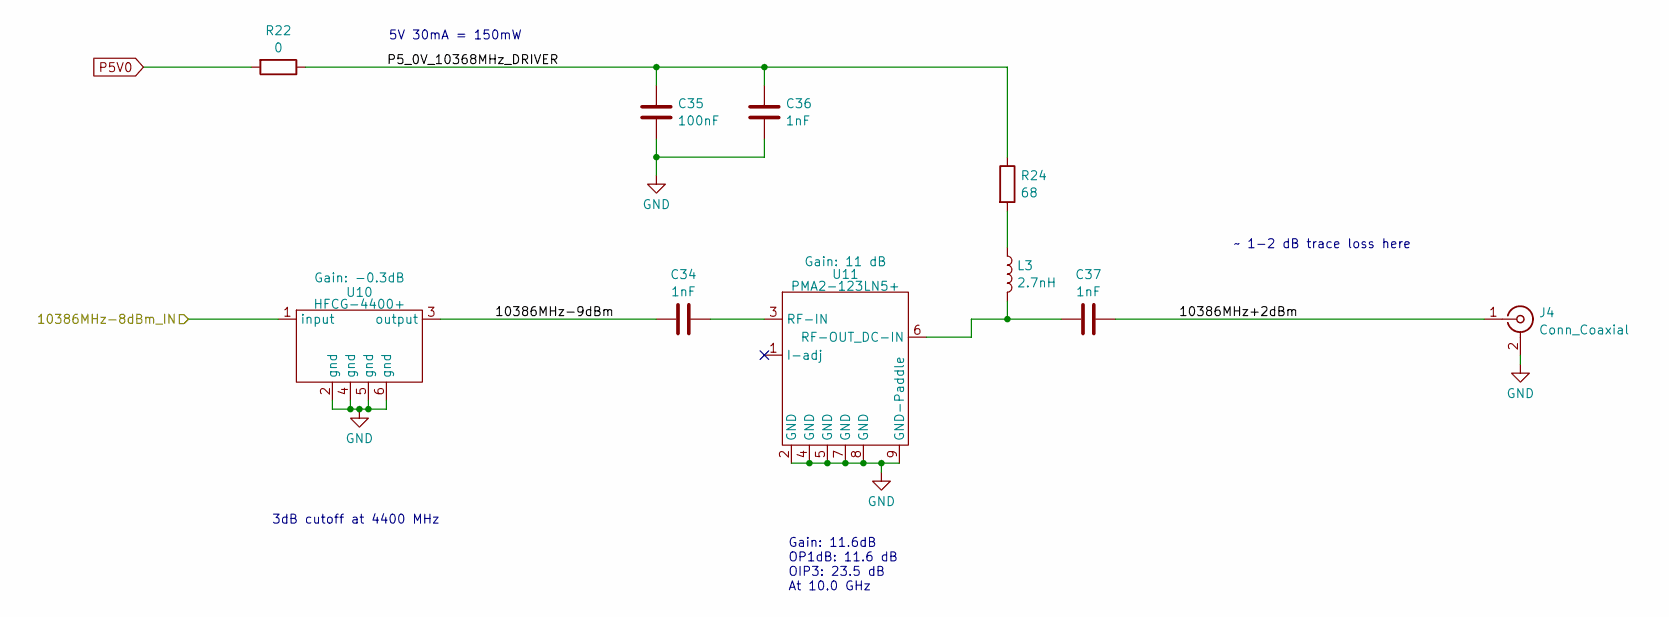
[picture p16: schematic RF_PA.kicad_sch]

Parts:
C34, C36, C37: 1nF; C_0402_1005Metric_Pad0.74x0.62mm_HandSolder
C35: 100nF; C_0603_1608Metric_Pad1.08x0.95mm_HandSolder
J4: Conn_Coaxial; SMA_Amphenol_901-143_Horizontal
L3: 2.7nH; L_0603_1608Metric_Pad1.05x0.95mm_HandSolder
R22: 0; R_0603_1608Metric_Pad0.98x0.95mm_HandSolder
R24: 68; R_2512_6332Metric_Pad1.40x3.35mm_HandSolder
U10: HFCG-4400+; Broadcom_DFN-6_2x2mm_P0.65mm
U11: PMA2-123LN5+; DFN-8-1EP_2x2mm_P0.5mm_EP0.6x1.2mm

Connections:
/3x_RF_Multiplier/10368MHz-8dBm_OUT: U10.1 (input); also elsewhere on the board
/RF_PA/10386MHz+2dBm: C37.1, J4.1 (In)
/RF_PA/10386MHz-9dBm: C34.1, U10.3 (output)
/RF_PA/P5_0V_10368MHz_DRIVER: C35.2, C36.2, R22.1, R24.1
GND: C35.1, C36.1, J4.2 (Ext), U10.2 (gnd), U10.4 (gnd), U10.5 (gnd), U10.6 (gnd), U11.2 (GND), U11.4 (GND), U11.5 (GND), U11.7 (GND), U11.8 (GND), U11.9 (GND-Paddle); also elsewhere on the board
unnamed: L3.1, R24.2
unnamed: C34.2, U11.3 (RF-IN)
unnamed: C37.2, L3.2, U11.6 (RF-OUT_DC-IN)
P5V0: R22.2; also elsewhere on the board

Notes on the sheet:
3dB cutoff at 4400 MHz
~ 1-2 dB trace loss here
5V 30mA = 150mW
Gain: 11.6dB OP1dB: 11.6 dB OIP3: 23.5 dB At 10.0 GHz

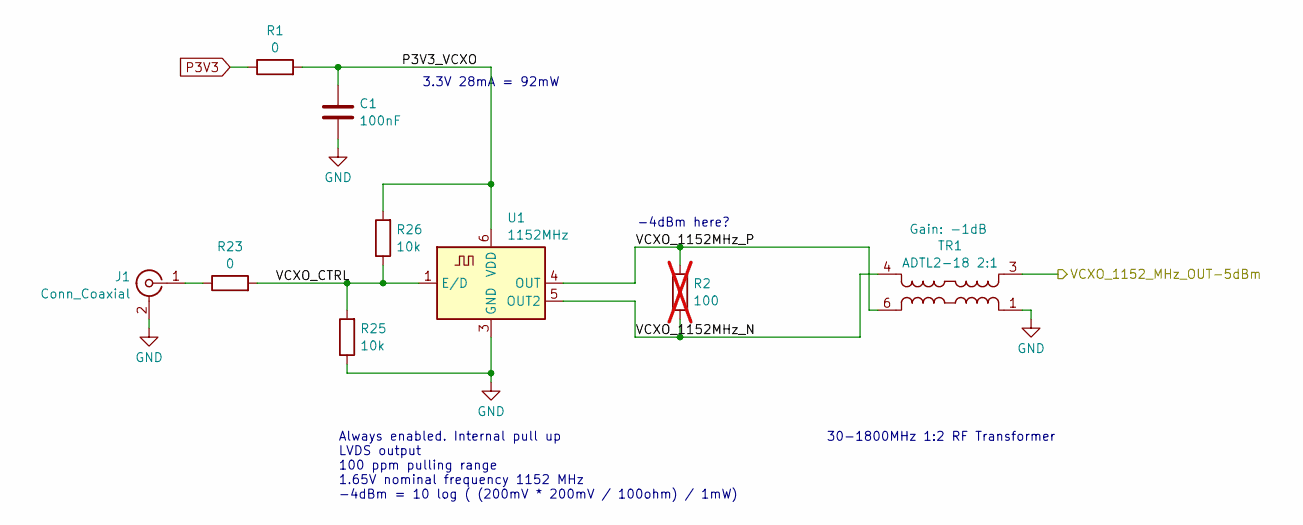
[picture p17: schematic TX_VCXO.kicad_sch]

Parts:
C1: 100nF; C_0603_1608Metric_Pad1.08x0.95mm_HandSolder
J1: Conn_Coaxial; BNC_Amphenol_B6252HB-NPP3G-50_Horizontal
R1, R23: 0; R_0603_1608Metric_Pad0.98x0.95mm_HandSolder
R2: 100; R_0603_1608Metric_Pad0.98x0.95mm_HandSolder; not fitted
R25, R26: 10k; R_0603_1608Metric_Pad0.98x0.95mm_HandSolder
TR1: ADTL2-18 2:1; Mini-Circuits_CD542_H2.84mm
U1: 1152MHz; Oscillator_SMD_IDT_JU6-6_7.0x5.0mm_P2.54mm

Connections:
/TX_VCXO/P3V3_VCXO: C1.1, R1.2, R26.2, U1.6 (VDD)
/TX_VCXO/VCXO_1152MHz_N: R2.2, TR1.4, U1.5 (OUT2)
/TX_VCXO/VCXO_1152MHz_P: R2.1, TR1.6, U1.4 (OUT)
/TX_VCXO/VCXO_1152_MHz_OUT-5dBm: TR1.3; also elsewhere on the board
/TX_VCXO/VCXO_CTRL: R23.2, R25.2, R26.1, U1.1 (E/D)
GND: C1.2, J1.2 (Ext), R25.1, TR1.1, U1.3 (GND); also elsewhere on the board
unnamed: J1.1 (In), R23.1
P3V3: R1.1; also elsewhere on the board

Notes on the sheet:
Always enabled. Internal pull up LVDS output 100 ppm pulling range 1.65V nominal frequency 1152 MHz -4dBm = 10 log ( (200mV * 200mV / 100ohm) / 1mW)
-4dBm here?
3.3V 28mA = 92mW
30-1800MHz 1:2 RF Transformer

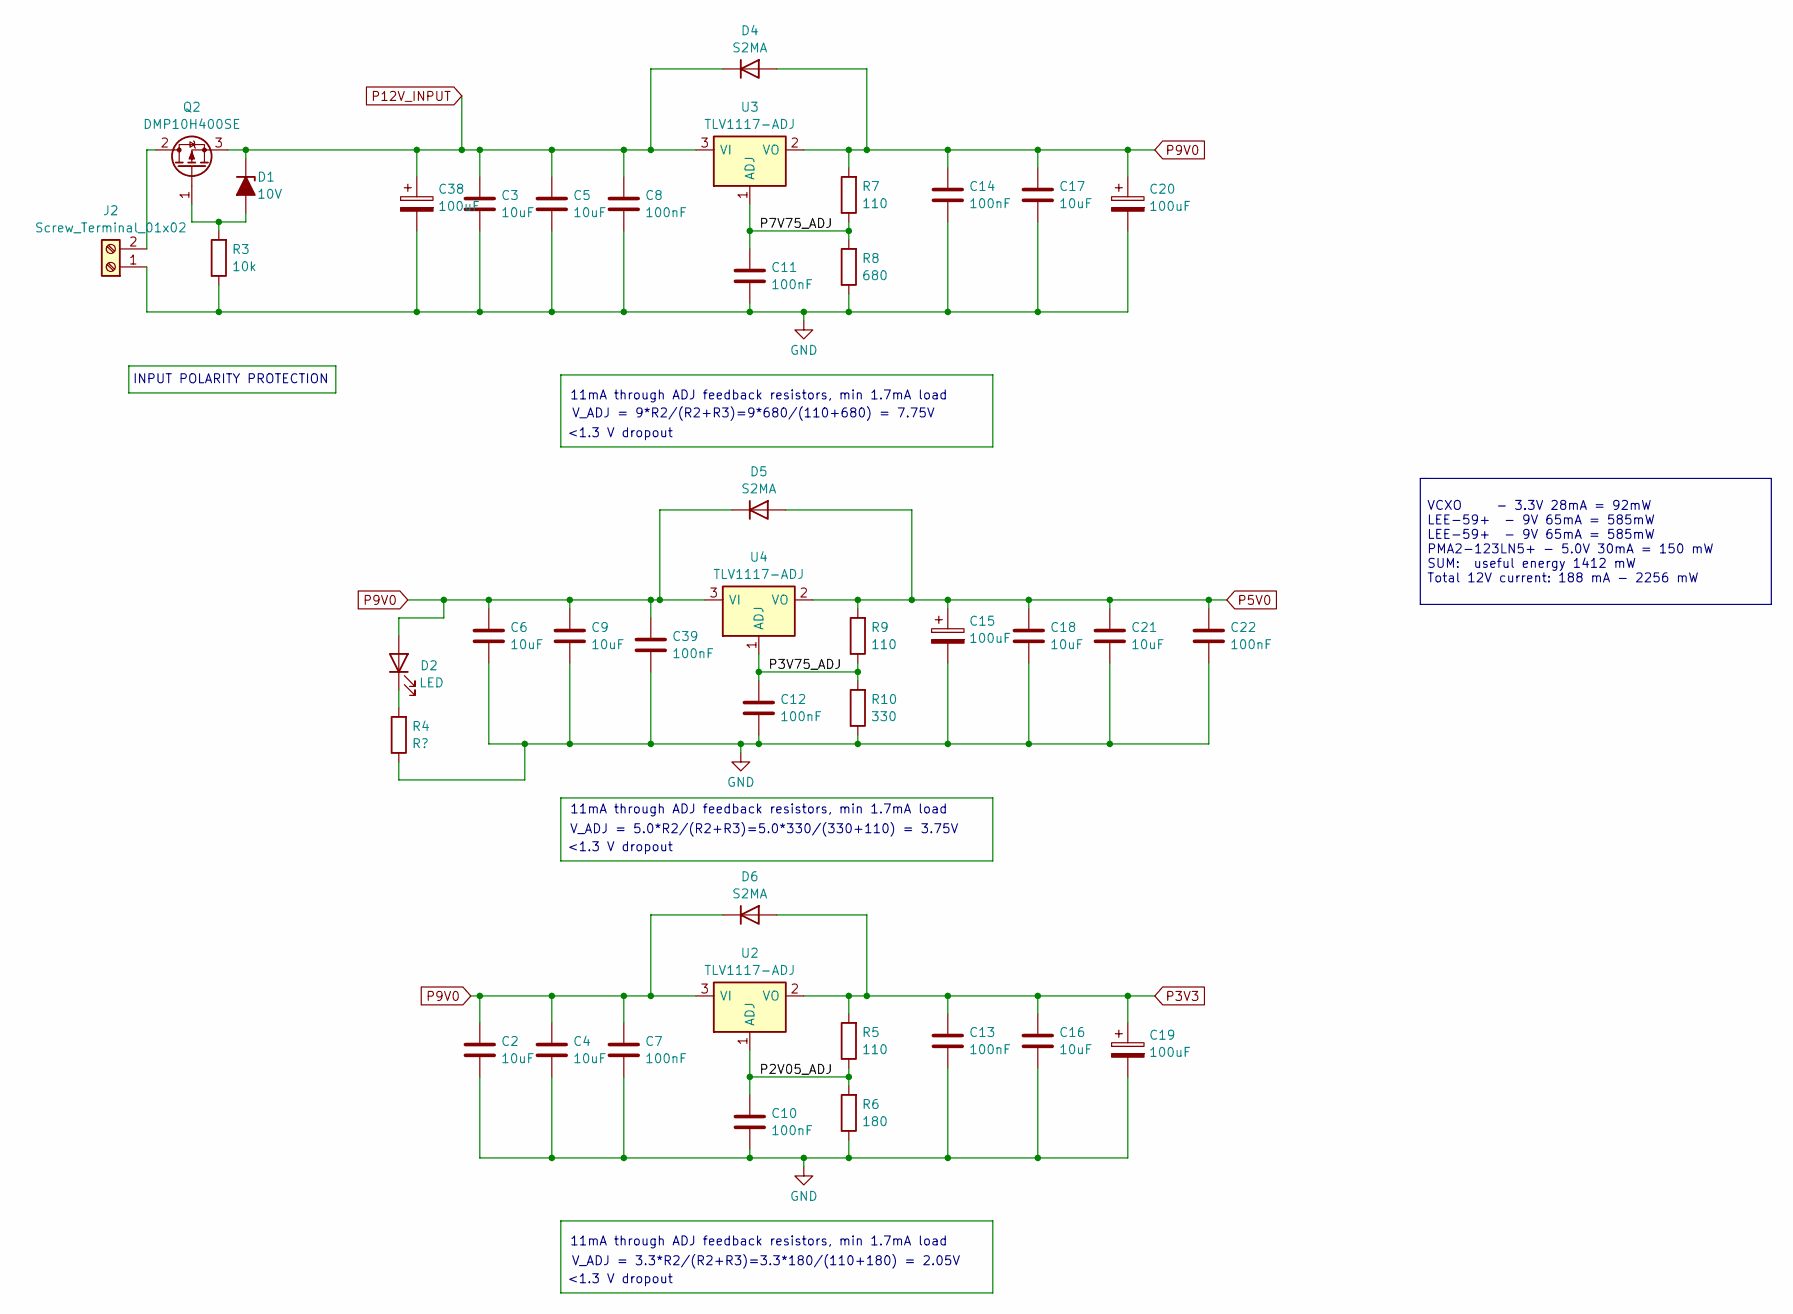
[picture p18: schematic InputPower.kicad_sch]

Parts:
C2, C3, C4, C5, C6, C9, C16, C17, C18, C21: 10uF; C_0805_2012Metric_Pad1.18x1.45mm_HandSolder
C7, C8, C10, C11, C12, C13, C14, C22, C39: 100nF; C_0603_1608Metric_Pad1.08x0.95mm_HandSolder
C15, C19, C20, C38: 100uF; CP_Elec_6.3x7.7
D1: 10V; D_SMA
D2: LED; LED_D3.0mm_Horizontal_O6.35mm_Z10.0mm
D4, D5, D6: S2MA; D_SMA
J2: Screw_Terminal_01x02; Altech_AK100_1x02_P5.00mm
Q2: DMP10H400SE; SOT-223-3_TabPin2
R3: 10k; R_0603_1608Metric_Pad0.98x0.95mm_HandSolder
R4: R?; R_0603_1608Metric_Pad0.98x0.95mm_HandSolder
R5, R7, R9: 110; R_0603_1608Metric_Pad0.98x0.95mm_HandSolder
R6: 180; R_0603_1608Metric_Pad0.98x0.95mm_HandSolder
R8: 680; R_0603_1608Metric_Pad0.98x0.95mm_HandSolder
R10: 330; R_0603_1608Metric_Pad0.98x0.95mm_HandSolder
U2, U3, U4: TLV1117-ADJ; SOT-223-3_TabPin2

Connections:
/InputPower/P2V05_ADJ: C10.2, R5.1, R6.2, U2.1 (ADJ)
/InputPower/P3V75_ADJ: C12.2, R9.1, R10.2, U4.1 (ADJ)
/InputPower/P7V75_ADJ: C11.2, R7.1, R8.2, U3.1 (ADJ)
GND: C2.1, C3.1, C4.1, C5.1, C6.1, C7.1, C8.1, C9.1, C10.1, C11.1, C12.1, C13.2, C14.1, C15.2, C16.2, C17.1, C18.1, C19.2, C20.2, C21.1, C22.1, C38.2, C39.1, J2.1, R3.1, R4.1, R6.1, R8.1, R10.1; also elsewhere on the board
unnamed: D1.2 (A), Q2.1 (G), R3.2
unnamed: D2.1 (K), R4.2
unnamed: J2.2, Q2.2 (D)
P3V3: C13.1, C16.1, C19.1, D6.2 (A), R5.2, U2.2 (VO); also elsewhere on the board
P5V0: C15.1, C18.2, C21.2, C22.2, D5.2 (A), R9.2, U4.2 (VO); also elsewhere on the board
P9V0: C2.2, C4.2, C6.2, C7.2, C9.2, C14.2, C17.2, C20.1, C39.2, D2.2 (A), D4.2 (A), D5.1 (K), D6.1 (K), R7.2, U2.3 (VI), U3.2 (VO), U4.3 (VI); also elsewhere on the board
P12V_INPUT: C3.2, C5.2, C8.2, C38.1, D1.1 (K), D4.1 (K), Q2.3 (S), U3.3 (VI)

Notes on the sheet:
<1.3 V dropout
11mA through ADJ feedback resistors, min 1.7mA load
V_ADJ = 9*R2/(R2+R3)=9*680/(110+680) = 7.75V
VCXO - 3.3V 28mA = 92mW LEE-59+ - 9V 65mA = 585mW LEE-59+ - 9V 65mA = 585mW PMA2-123LN5+ - 5.0V 30mA = 150 mW SUM: useful energy 1412 mW Total 12V current: 188 mA - 2256 mW
INPUT POLARITY PROTECTION
V_ADJ = 5.0*R2/(R2+R3)=5.0*330/(330+110) = 3.75V
V_ADJ = 3.3*R2/(R2+R3)=3.3*180/(110+180) = 2.05V

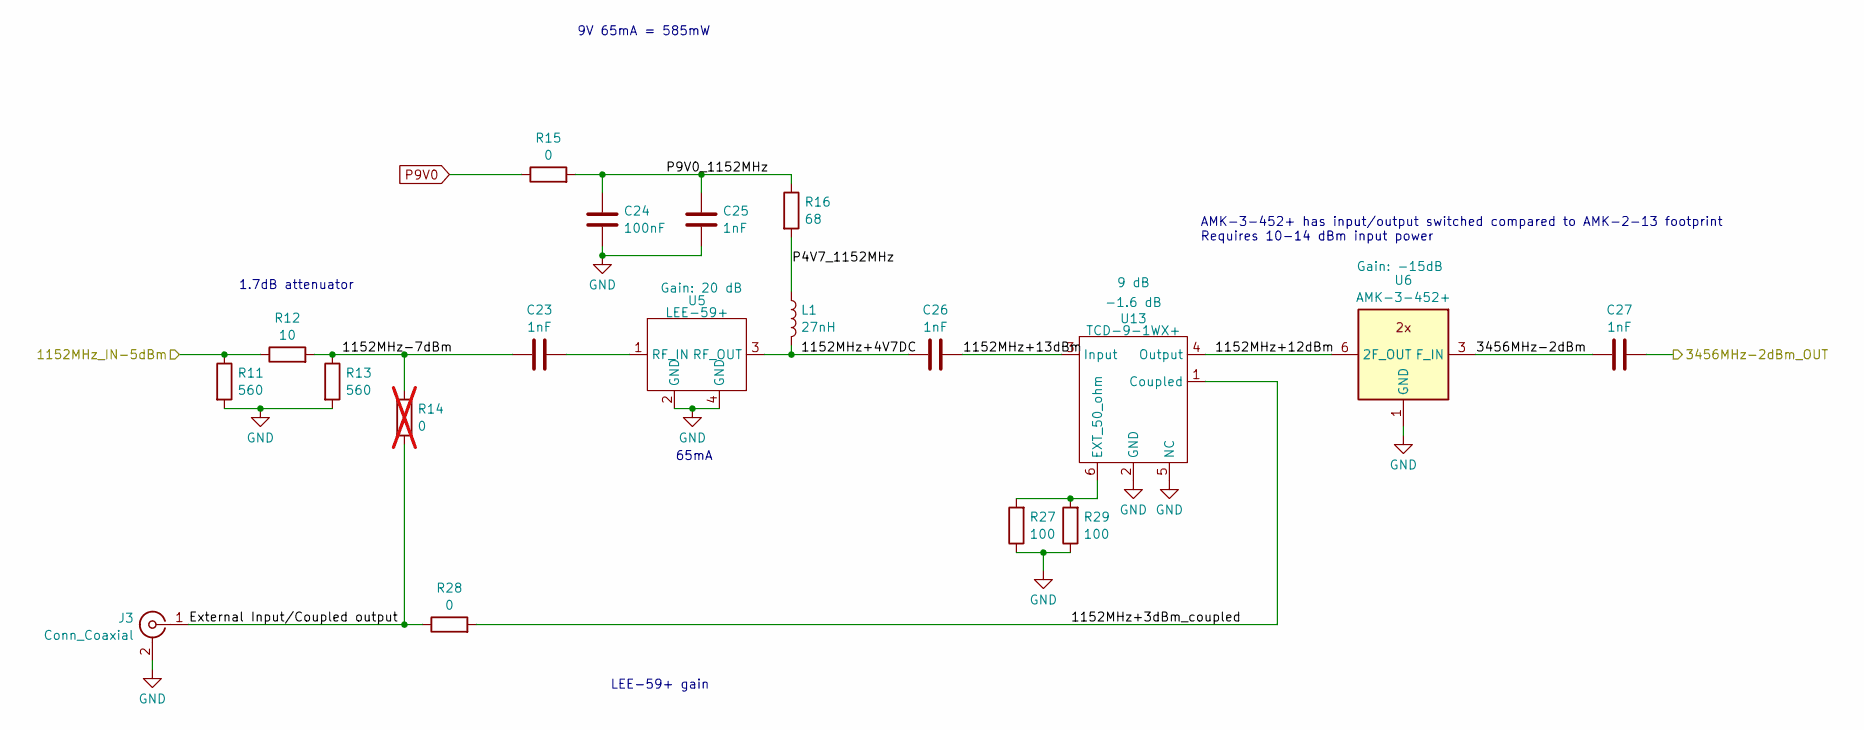
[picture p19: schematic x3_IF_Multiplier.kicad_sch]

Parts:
C23, C25, C26, C27: 1nF; C_0402_1005Metric_Pad0.74x0.62mm_HandSolder
C24: 100nF; C_0603_1608Metric_Pad1.08x0.95mm_HandSolder
J3: Conn_Coaxial; SMA_Amphenol_901-143_Horizontal
L1: 27nH; L_0603_1608Metric_Pad1.05x0.95mm_HandSolder
R11, R13: 560; R_0603_1608Metric_Pad0.98x0.95mm_HandSolder
R12: 10; R_0603_1608Metric_Pad0.98x0.95mm_HandSolder
R14: 0; R_0603_1608Metric_Pad0.98x0.95mm_HandSolder; not fitted
R15, R28: 0; R_0603_1608Metric_Pad0.98x0.95mm_HandSolder
R16: 68; R_2512_6332Metric_Pad1.40x3.35mm_HandSolder
R27, R29: 100; R_0603_1608Metric_Pad0.98x0.95mm_HandSolder
U5: LEE-59+; Mini-Circuits_FG873-4_3x3mm
U6: AMK-3-452+; Mini-Circuits_CD542_LandPatternPL-052
U13: TCD-9-1WX+; Mini-Circuits_DB1627

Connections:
/3x_RF_Multiplier/3456MHz-2dBm_IN: C27.2; also elsewhere on the board
/TX_VCXO/VCXO_1152_MHz_OUT-5dBm: R11.1, R12.1; also elsewhere on the board
/x3_IF_Multiplier/1152MHz+3dBm_coupled: R28.2, U13.1 (Coupled)
/x3_IF_Multiplier/1152MHz+4V7DC: C26.1, L1.2, U5.3 (RF_OUT)
/x3_IF_Multiplier/1152MHz+12dBm: U6.6 (2F_OUT), U13.4 (Output)
/x3_IF_Multiplier/1152MHz+13dBm: C26.2, U13.3 (Input)
/x3_IF_Multiplier/1152MHz-7dBm: C23.1, R12.2, R13.1, R14.1
/x3_IF_Multiplier/3456MHz-2dBm: C27.1, U6.3 (F_IN)
/x3_IF_Multiplier/External Input/Coupled output: J3.1 (In), R14.2, R28.1
/x3_IF_Multiplier/P4V7_1152MHz: L1.1, R16.2
/x3_IF_Multiplier/P9V0_1152MHz: C24.2, C25.2, R15.2, R16.1
GND: C24.1, C25.1, J3.2 (Ext), R11.2, R13.2, R27.1, R29.1, U5.2 (GND), U5.4 (GND), U6.1 (GND), U6.4 (GND), U6.5 (GND), U13.2 (GND), U13.5 (NC); also elsewhere on the board
unnamed: C23.2, U5.1 (RF_IN)
unnamed: R27.2, R29.2, U13.6 (EXT_50_ohm)
P9V0: R15.1; also elsewhere on the board

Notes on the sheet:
AMK-3-452+ has input/output switched compared to AMK-2-13 footprint Requires 10-14 dBm input power
9V 65mA = 585mW
1.7dB attenuator
LEE-59+ gain
65mA

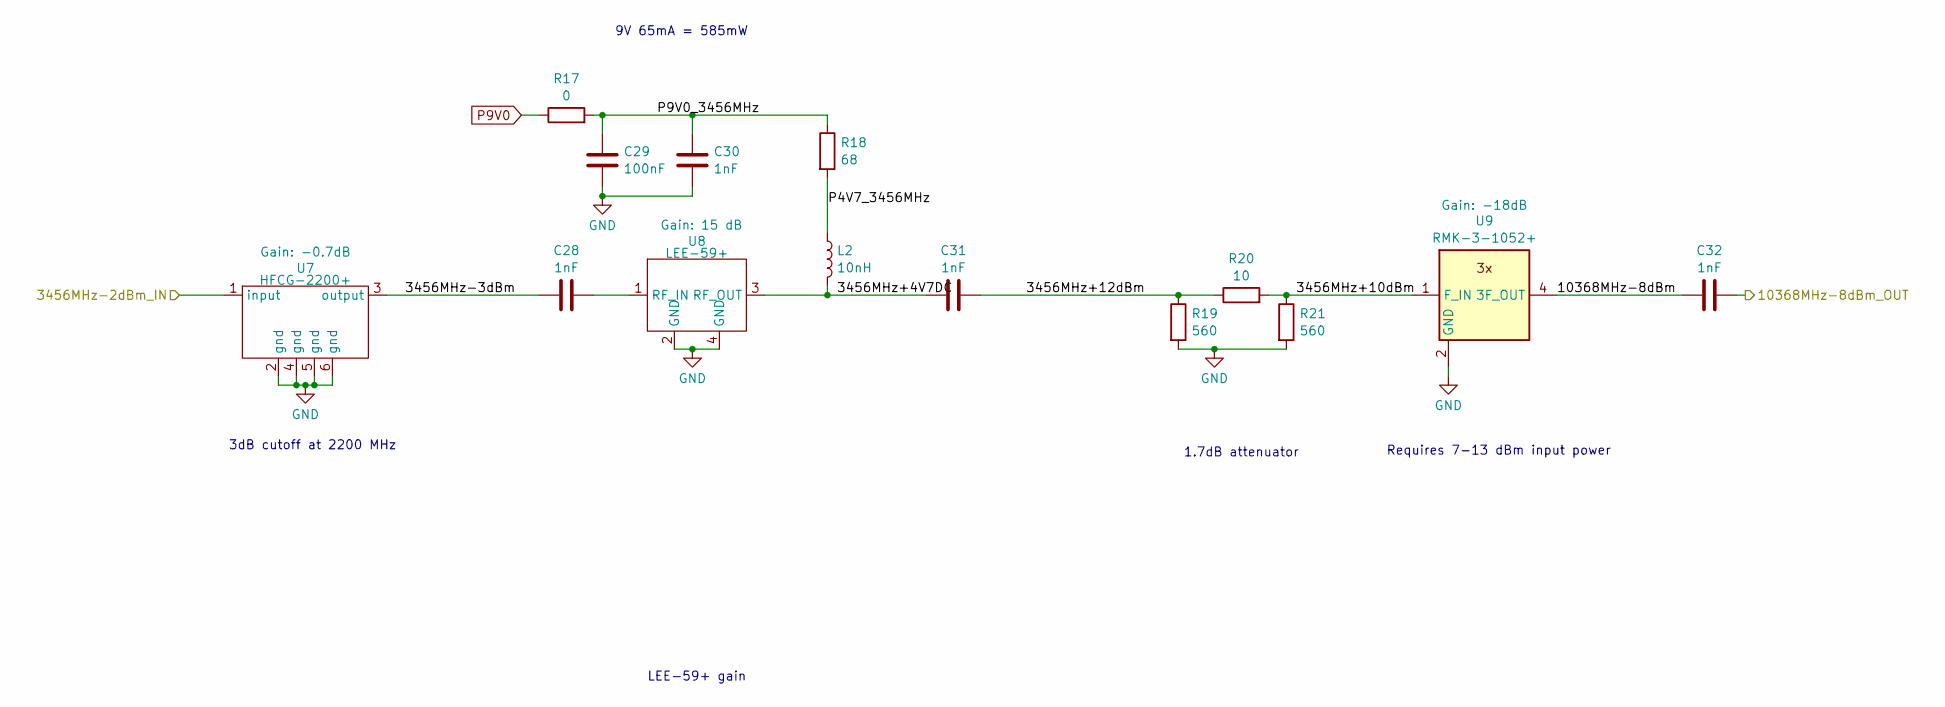
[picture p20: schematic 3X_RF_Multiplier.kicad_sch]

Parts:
C28, C30, C31, C32: 1nF; C_0402_1005Metric_Pad0.74x0.62mm_HandSolder
C29: 100nF; C_0603_1608Metric_Pad1.08x0.95mm_HandSolder
L2: 10nH; L_0603_1608Metric_Pad1.05x0.95mm_HandSolder
R17: 0; R_0603_1608Metric_Pad0.98x0.95mm_HandSolder
R18: 68; R_2512_6332Metric_Pad1.40x3.35mm_HandSolder
R19, R21: 560; R_0603_1608Metric_Pad0.98x0.95mm_HandSolder
R20: 10; R_0603_1608Metric_Pad0.98x0.95mm_HandSolder
U7: HFCG-2200+; Broadcom_DFN-6_2x2mm_P0.65mm
U8: LEE-59+; Mini-Circuits_FG873-4_3x3mm
U9: RMK-3-1052+; Mini-Circuits_TT1224_LandPatternPL-258_ClockwisePinNumbering

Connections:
/3x_RF_Multiplier/3456MHz+4V7DC: C31.2, L2.2, U8.3 (RF_OUT)
/3x_RF_Multiplier/3456MHz+10dBm: R20.2, R21.1, U9.1 (F_IN)
/3x_RF_Multiplier/3456MHz+12dBm: C31.1, R19.1, R20.1
/3x_RF_Multiplier/3456MHz-2dBm_IN: U7.1 (input); also elsewhere on the board
/3x_RF_Multiplier/3456MHz-3dBm: C28.1, U7.3 (output)
/3x_RF_Multiplier/10368MHz-8dBm: C32.1, U9.4 (3F_OUT)
/3x_RF_Multiplier/10368MHz-8dBm_OUT: C32.2; also elsewhere on the board
/3x_RF_Multiplier/P4V7_3456MHz: L2.1, R18.2
/3x_RF_Multiplier/P9V0_3456MHz: C29.2, C30.2, R17.2, R18.1
GND: C29.1, C30.1, R19.2, R21.2, U7.2 (gnd), U7.4 (gnd), U7.5 (gnd), U7.6 (gnd), U8.2 (GND), U8.4 (GND), U9.2 (GND), U9.3 (GND), U9.5 (GND), U9.6 (GND); also elsewhere on the board
unnamed: C28.2, U8.1 (RF_IN)
P9V0: R17.1; also elsewhere on the board

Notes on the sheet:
1.7dB attenuator
Requires 7-13 dBm input power
9V 65mA = 585mW
LEE-59+ gain
3dB cutoff at 2200 MHz

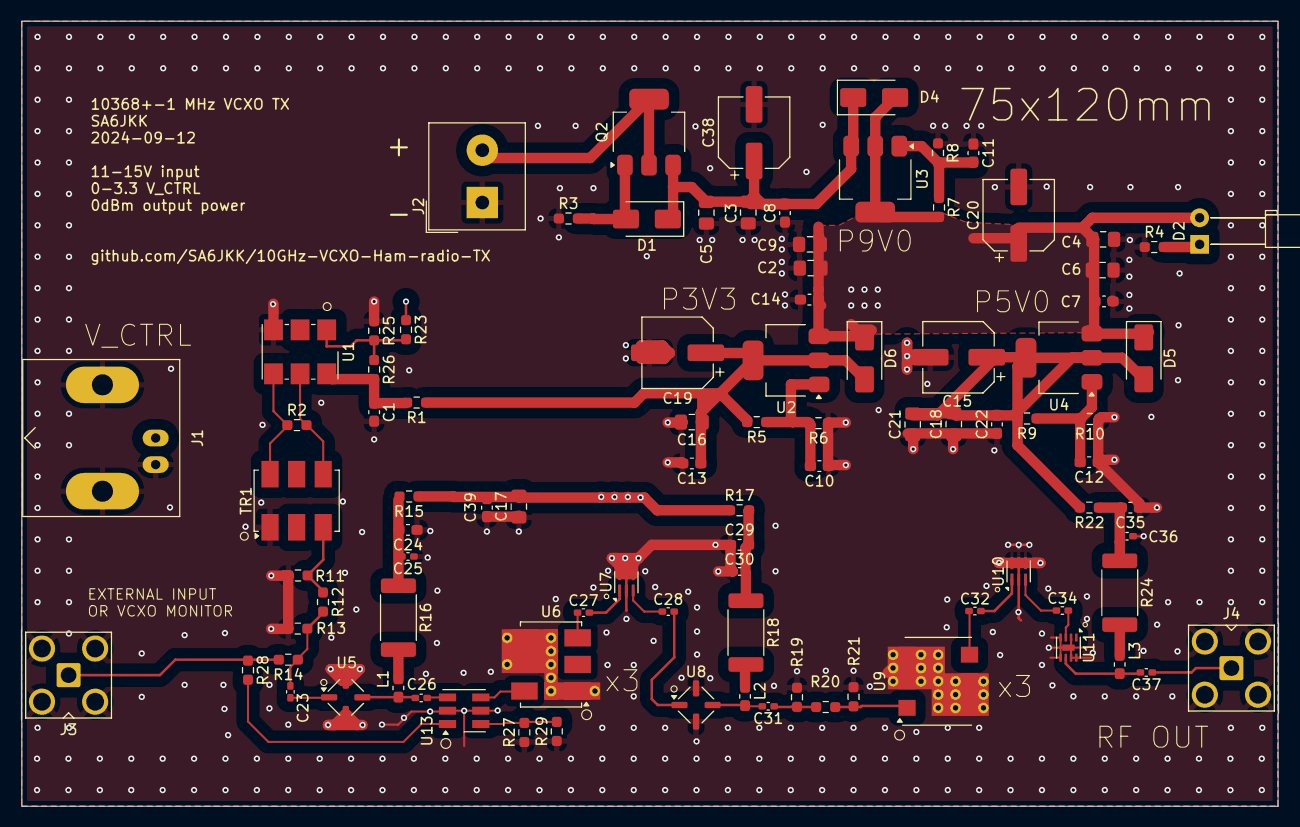
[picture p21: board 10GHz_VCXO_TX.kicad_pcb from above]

Board: 4 copper layers, 120.0 x 75.0 mm, 93 parts (0 on the bottom side), 44 nets.

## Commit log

2024-06-20 Start project!
    LDO + VCXO
    [10GHz_VCXO_TX.kicad_pcb, 10GHz_VCXO_TX.kicad_sch]
2024-06-21 Add multipliers
    [10GHz_VCXO_TX.kicad_pcb, 10GHz_VCXO_TX.kicad_sch]
2024-06-23 Update Hierarchy + LEE-59+
    [10GHz_VCXO_TX.kicad_pcb, 10GHz_VCXO_TX.kicad_sch, 3X_RF_Multiplier.kicad_sch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]
2024-06-23 add LEE-59+ footprint
    [10GHz_VCXO_TX.kicad_pcb, 3X_RF_Multiplier.kicad_sch, TX_VCXO.kicad_sch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]
2024-06-24 Update README.md with enclosure
2024-06-24 Update board outline, floorplan and tidy up
    [10GHz_VCXO_TX.kicad_pcb, 10GHz_VCXO_TX.kicad_sch, 3X_RF_Multiplier.kicad_sch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]
2024-06-24 Add BOM cost analysis
    [10GHz_VCXO_TX_BOM.csv, 10GHz_VCXO_TX_BOM_Analysis.ods]
2024-06-26 Add HP filters after multiplier
    [10GHz_VCXO_TX.kicad_pcb, 10GHz_VCXO_TX.kicad_sch, 3X_RF_Multiplier.kicad_sch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]
2024-06-30 Add PMA2-123LN5+
    [10GHz_VCXO_TX.kicad_pcb, 10GHz_VCXO_TX.kicad_sch, 3X_RF_Multiplier.kicad_sch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]
2024-07-05 Add PA HMC952A & LED
    [10GHz_VCXO_TX.kicad_pcb, InputPower.kicad_sch, RF_PA.kicad_sch]
2024-07-06 Add optional external oscillator input
    [10GHz_VCXO_TX.kicad_pcb, x3_IF_Multiplier.kicad_sch]
2024-07-07 Add 5V Linear Regulator
    [10GHz_VCXO_TX.kicad_pcb, InputPower.kicad_sch, RF_PA.kicad_sch]
2024-07-07 Fixed power consumption calculation
    [InputPower.kicad_sch]
2024-07-23 Add more decoupling & tidying of schematic
    [10GHz_VCXO_TX.kicad_pcb, 3X_RF_Multiplier.kicad_sch, InputPower.kicad_sch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]
2024-07-28 Finished schematic, update BOM cost analysis
    ~1000 kr components.
    [10GHz_VCXO_TX.kicad_pcb, 10GHz_VCXO_TX_BOM.csv, 10GHz_VCXO_TX_BOM_Analysis.ods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]
2024-07-28 Finalize placing, initial routing, schematic tidying
    [10GHz_VCXO_TX.kicad_pcb, 3X_RF_Multiplier.kicad_sch, InputPower.kicad_sch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]
2024-07-28 Initial routing complete
    [10GHz_VCXO_TX.kicad_pcb]
2024-07-29 Added more documentation to schematic
    [10GHz_VCXO_TX.kicad_pcb, 3X_RF_Multiplier.kicad_sch, RF_PA.kicad_sch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]
2024-07-30 Update inductor component values schematic
    [10GHz_VCXO_TX.kicad_sch, 3X_RF_Multiplier.kicad_sch, InputPower.kicad_sch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]
2024-08-07 10uF 0603 -> 10uF 0805
    [10GHz_VCXO_TX.kicad_pcb, InputPower.kicad_sch]
2024-08-08 Add schematic pdf and layout assembly pdf
    [untitled.kicad_sch]
2024-08-14 Add layout copper fill
    and update origin, bigger electrolytics
    [10GHz_VCXO_TX.kicad_pcb, InputPower.kicad_sch]
2024-08-19 Add via stitching and remove edge solder mask
    [10GHz_VCXO_TX.kicad_pcb]
2024-08-19 Add silk screen text to connectors
    [10GHz_VCXO_TX.kicad_pcb]
2024-08-23 Update BOM with ordering status
    [10GHz_VCXO_TX_BOM.csv, 10GHz_VCXO_TX_BOM_Analysis.ods]
2024-08-23 Add github link text
    [10GHz_VCXO_TX.kicad_pcb]
2024-08-24 Removed solder mask over 10 GHz traces
    [10GHz_VCXO_TX.kicad_pcb]
2024-08-29 Remove more solder mask
    [10GHz_VCXO_TX.kicad_pcb]
2024-08-30 Prepare for TCD-9-1WX+ addition
    To enable buffered VCXO output for frequency counter
    [10GHz_VCXO_TX.kicad_pcb, x3_IF_Multiplier.kicad_sch]
2024-08-30 Add TCD-9-1WX+ coupler for frequency measurements
    [10GHz_VCXO_TX.kicad_pcb, x3_IF_Multiplier.kicad_sch]
2024-09-08 Add 9 dB coupler for VCXO monitor to layout
    [10GHz_VCXO_TX.kicad_pcb, x3_IF_Multiplier.kicad_sch]
2024-09-09 Tidying up layout and new render
    [10GHz_VCXO_TX.kicad_pcb, RF_PA.kicad_sch]
2024-09-10 Update plots
    [x3_IF_Multiplier.kicad_sch]
2024-09-10 Add more GND vias
    [10GHz_VCXO_TX.kicad_pcb]
2024-09-12 Final touches before ordering
    [10GHz_VCXO_TX.kicad_pcb, RF_PA.kicad_sch, TX_VCXO.kicad_sch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]
2024-09-12 Updated date of board
    [10GHz_VCXO_TX.kicad_pcb]
2024-09-14 Update plots folder
    [10GHz_VCXO_TX.kicad_sch]
2024-09-28 Add interactive BOM for assembly
2024-09-28 Add first test report and assembled image
2024-10-26 Update 1152 MHz attenuator
    [10GHz_VCXO_TX.kicad_sch, TX_VCXO.kicad_sch, x3_IF_Multiplier.kicad_sch]
2024-12-03 Create RF-calculations for 10 GHz lineup
    [RF-calculations.ods]
2025-02-25 Updating TODO in schematic
    [RF_PA.kicad_sch]
2025-02-25 Update RF-calculations again
    [RF-calculations.ods]
